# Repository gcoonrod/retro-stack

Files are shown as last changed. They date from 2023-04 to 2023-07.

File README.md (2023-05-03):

# retro-stack

A retro computer project based on stackable PCB boards. This project was largely inspired by Ben Eater's 6502 breadboard computer project.

## Project Objective

Design, prototype, and build an 8 bit computer roughly comparable to an Apple II or NES in capabilities.

### Hardware Design Goals

Create an 8 bit computer with the following basic capabilities:

- Stable at or near maximum frequency of the processor
- Modular (including reconfigurable address map)
- Character display via RS-232 Serial and LCD
- PS/2 Keyboard Input

Optional:

- Sound generation
- VGA video output
- 10baseT ethernet

### Software Design Goals

- Develop a strong understanding of Assembly programming
- Understand and implement the following protocols:
  - UART
  - SPI
  - PS/2
- Learn the basics of PLDs and CUPL to use in "glue logic"
- Develop a moderate to strong understanding of Atmel AVR MCU programming
- Implement a simple Operating System within the constraints of an 8 bit architecture
- Understand and implement both software and hardware interrupts

## Repository Layout

This repository contains all of the hardware and software assets in the following structure:

- [Hardware Schematics and PCB Layouts](./boards/)
- [Firmware](./firmware/)
- Tooling (TBD)
- Documentation (TBD)s

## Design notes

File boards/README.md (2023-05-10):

<!--
 Copyright 2023 Greg Coonrod
 
 Licensed under the Apache License, Version 2.0 (the "License");
 you may not use this file except in compliance with the License.
 You may obtain a copy of the License at
 
     http://www.apache.org/licenses/LICENSE-2.0
 
 Unless required by applicable law or agreed to in writing, software
 distributed under the License is distributed on an "AS IS" BASIS,
 WITHOUT WARRANTIES OR CONDITIONS OF ANY KIND, either express or implied.
 See the License for the specific language governing permissions and
 limitations under the License.
-->

# RetroStack - Boards

The RetroStack project currently includes the following boards based on a common [template](./retro-stack-template/):

- [Power Supply & 555 Clock](./retro-stack-power-clock/)
- [W65C02S CPU & High Speed Clock](./retro-stack-cpu/)
- [SRAM & ROM](./retro-stack-ram-rom/)
- [Arduino Mega Debug Shield](./retro-stack-debug-arduino-mega-shield/)
- [Debug & Status Display](./retro-stack-debug/)

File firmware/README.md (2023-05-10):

<!--
 Copyright 2023 Greg Coonrod
 
 Licensed under the Apache License, Version 2.0 (the "License");
 you may not use this file except in compliance with the License.
 You may obtain a copy of the License at
 
     http://www.apache.org/licenses/LICENSE-2.0
 
 Unless required by applicable law or agreed to in writing, software
 distributed under the License is distributed on an "AS IS" BASIS,
 WITHOUT WARRANTIES OR CONDITIONS OF ANY KIND, either express or implied.
 See the License for the specific language governing permissions and
 limitations under the License.
-->

# RetroStack Firmware

The RetroStack computer includes a W65C02S processor, PLDs, and Arduinos. Each of these components need software or firmware in order to operate. This folder contains that software broken up by logical "programs" or use-cases.

## Development and Debugging Utilities

- [Monitor](./arduino/monitor/) - Arduino Mega2560 based bus monitor and ROM emulator.
- [PLD Tester](./arduino/pld-tester/) - Arduino Nano Every based tool for testing an AT16V8B PLD.

## Programmable Logic

- [Address Decode](./pld/address-decode/) - CUPL files for the various PLDs.

## 6502 Applications

- [Memory Tester](./6502/memory-test/) - Verify current RAM/ROM address map.
- [IO Test](./6502/io-test/) - Use an LED bar and W65C22 VIA to display the output of an 8-bit counter.

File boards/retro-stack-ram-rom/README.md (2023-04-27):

<!--
 Copyright 2023 Greg Coonrod
 
 Licensed under the Apache License, Version 2.0 (the "License");
 you may not use this file except in compliance with the License.
 You may obtain a copy of the License at
 
     http://www.apache.org/licenses/LICENSE-2.0
 
 Unless required by applicable law or agreed to in writing, software
 distributed under the License is distributed on an "AS IS" BASIS,
 WITHOUT WARRANTIES OR CONDITIONS OF ANY KIND, either express or implied.
 See the License for the specific language governing permissions and
 limitations under the License.
-->

# RetroStack - RAM & ROM Module

This module contains RAM, ROM, and a PLD for address decoding.

## Schematic

Current schematic [pdf](./assets/schematic.pdf).

## PCB Layout & Render

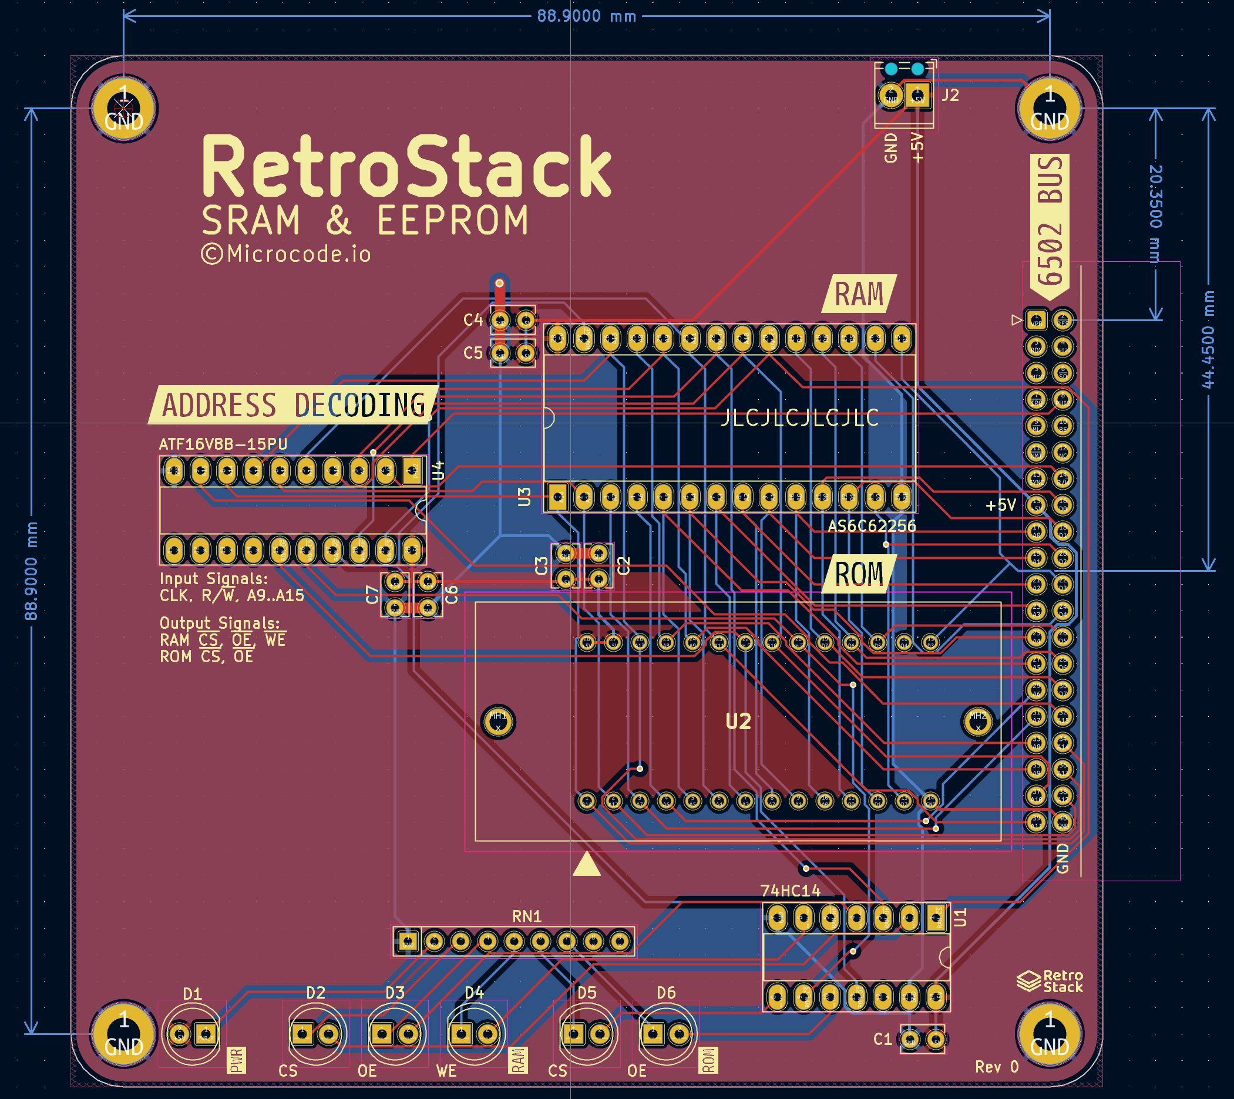
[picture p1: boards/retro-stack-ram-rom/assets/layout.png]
layout


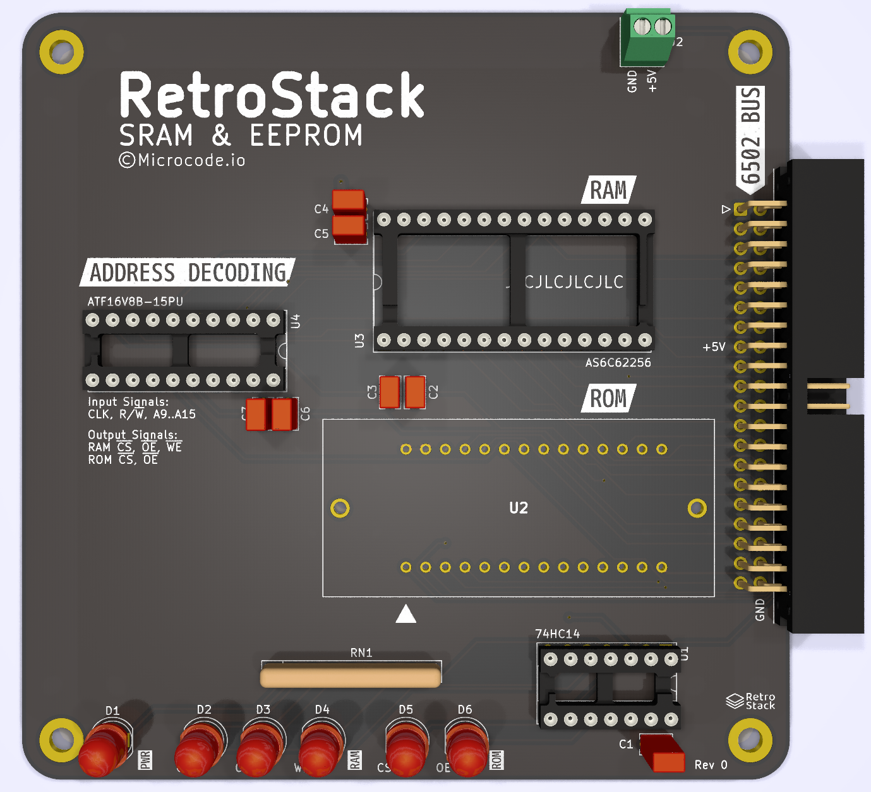
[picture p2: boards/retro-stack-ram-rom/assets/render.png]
render


## Known Issues

N/A

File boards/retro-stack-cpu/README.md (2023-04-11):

# RetroStack - W65C02S CPU & High Speed Clock Module

This module contains the W65C02S CPU, a selectable high speed oscillator, and a selectable DS1813 reset signal manager.

## Schematic

Current schematic [pdf](./assets/schematic.pdf).

## PCB Layout & Render

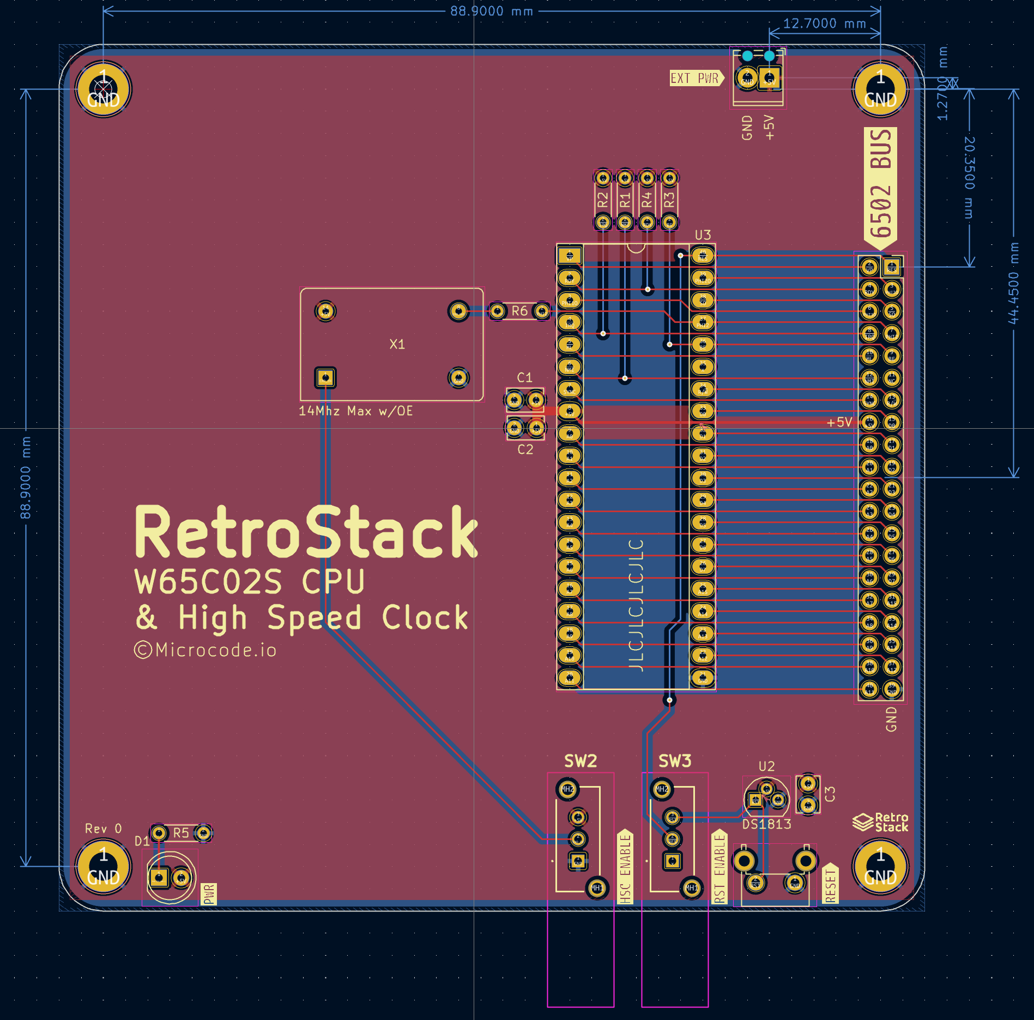
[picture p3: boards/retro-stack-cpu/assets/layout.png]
layout


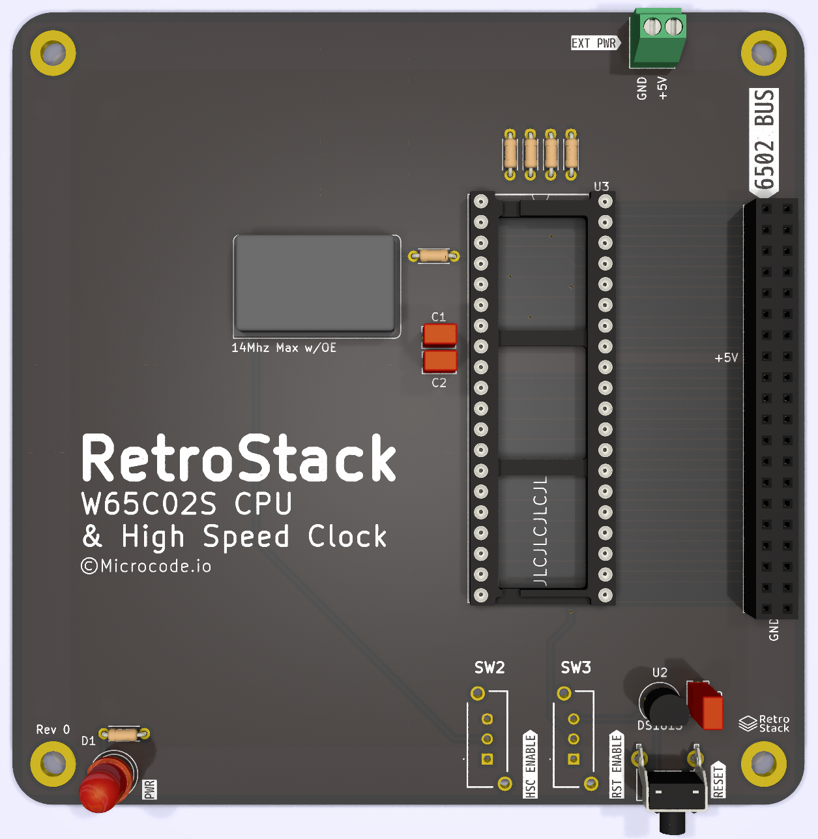
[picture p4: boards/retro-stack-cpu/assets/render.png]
render


## Known Issues

N/A

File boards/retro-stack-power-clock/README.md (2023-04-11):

# RetroStack - Power & Clock Module

This module is based on the 555 clock circuit used in Ben Eater's 8-bit and 6502 computer projects.

## Schematic

Current schematic [pdf](./assets/schematic.pdf).

## PCB Layout & Render

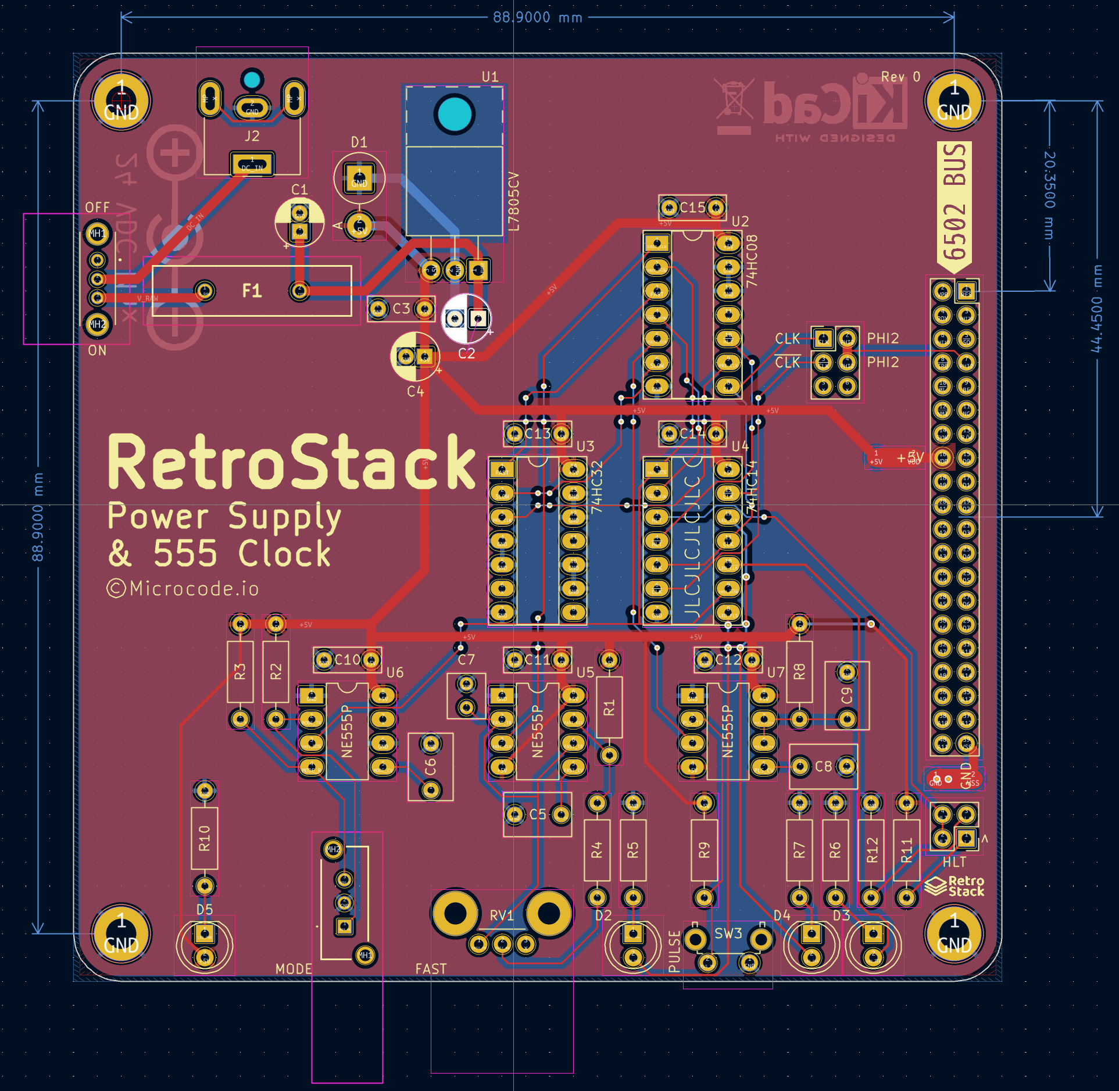
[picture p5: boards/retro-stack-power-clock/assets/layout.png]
layout


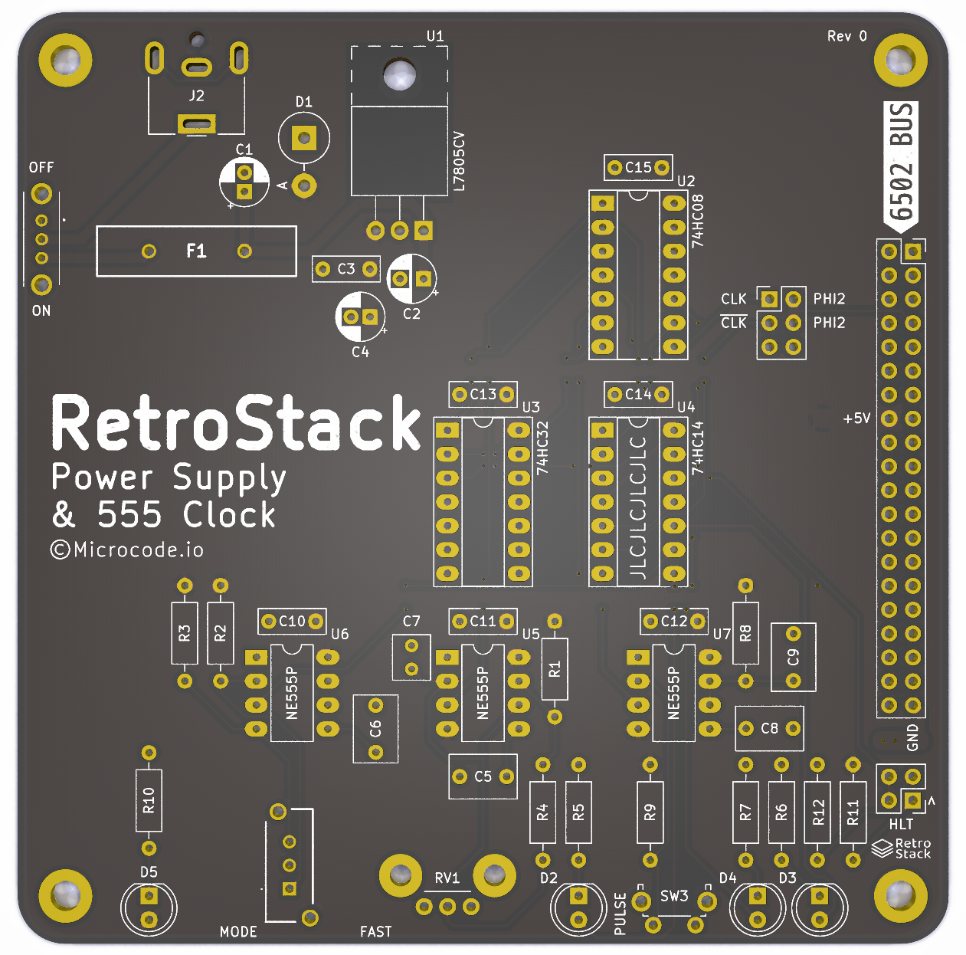
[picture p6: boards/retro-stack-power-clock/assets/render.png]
render


## Known Issues

- PTC is oversized.
- TVS diode is oversized.
- Need knob for RV1.
- Need 2.54mm pitch header jumpers.
- Add more detail to silkscreen.
- Remove Net ties.

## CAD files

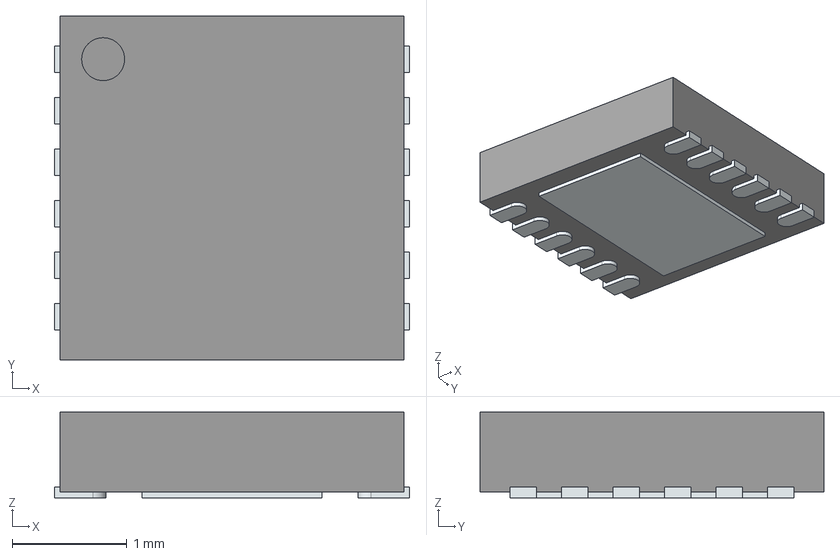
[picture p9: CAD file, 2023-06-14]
boards/parts/3D/FT234XD-R.step
3.10 x 3.00 x 0.75 mm
ThermalPin
PinsArrayLR

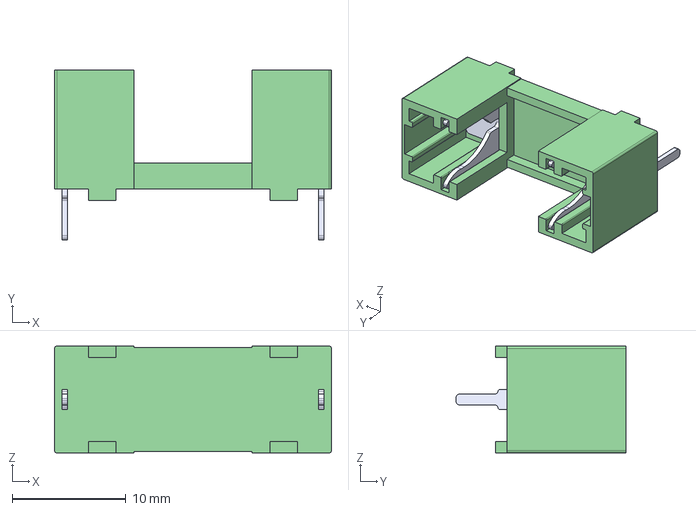
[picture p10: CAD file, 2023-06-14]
boards/parts/3D/0PTF0078P.step
24.4 x 15.0 x 9.40 mm

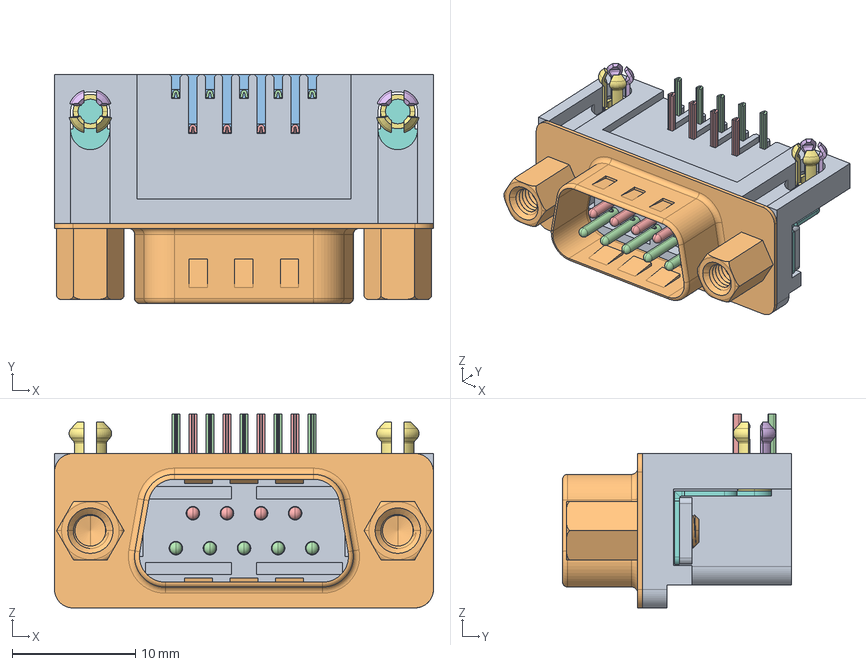
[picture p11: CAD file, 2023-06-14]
boards/parts/3D/L717SDE09PA4CH3F.step
30.8 x 18.6 x 15.8 mm
MALE
COVER
TERMINAL-22 x 5
TERMINAL-11 x 4
YUCHA x 2
CLINTNUT-7 x 2
SCREW x 2

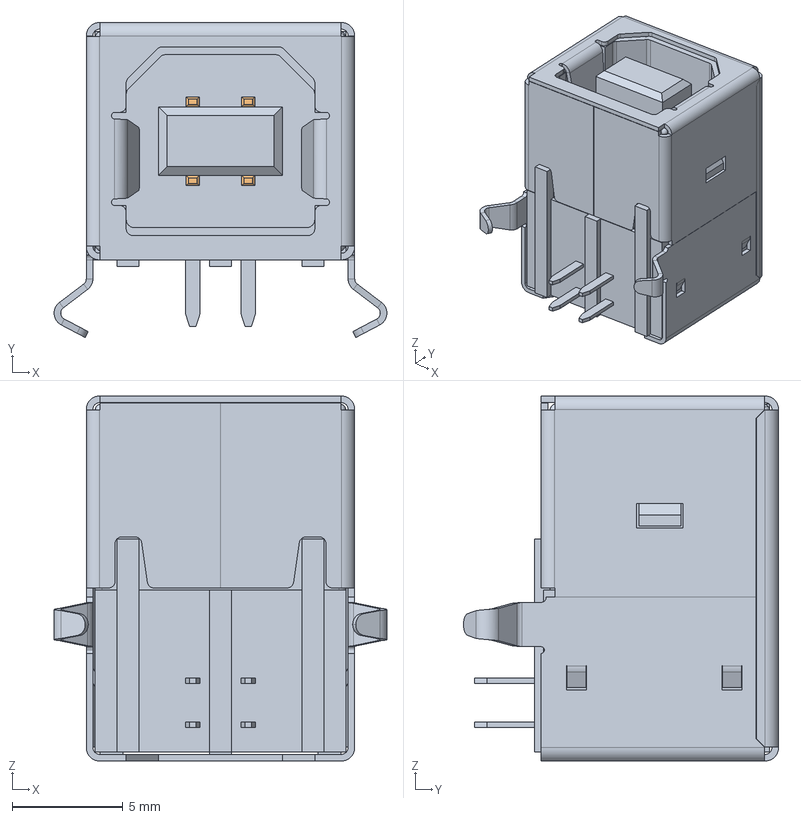
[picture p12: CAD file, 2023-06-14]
boards/parts/3D/UJ2-BH-1-TH.step
15.0 x 14.2 x 16.5 mm

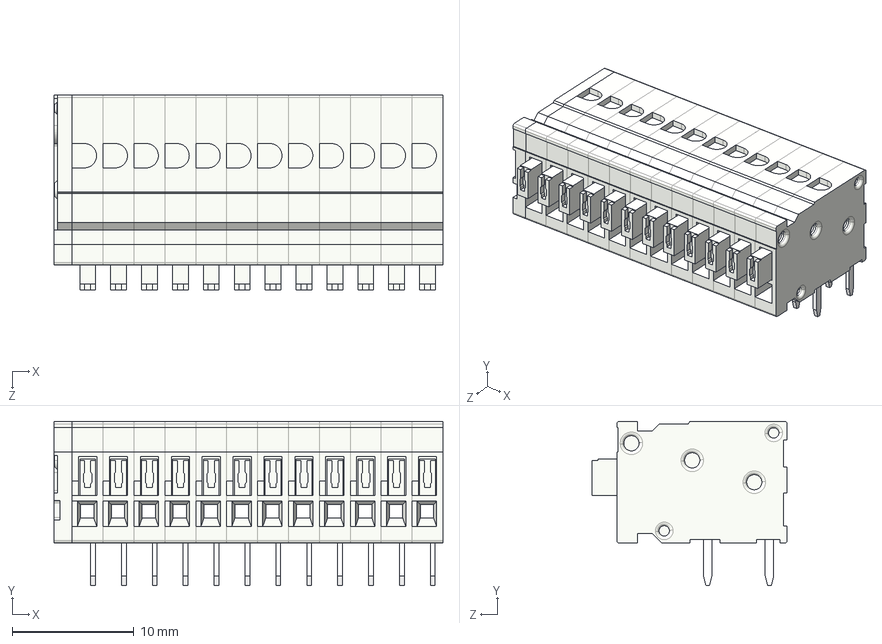
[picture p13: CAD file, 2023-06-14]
boards/parts/3D/CUI_DEVICES_TBL009-254-12GY-2GY.step
32.0 x 13.5 x 16.1 mm
TBL009-254 - END CAP_Gray
TBL009-254 - BODY_Gray x 12
TBL009-254 - PUSH BUTTON_Gray x 12

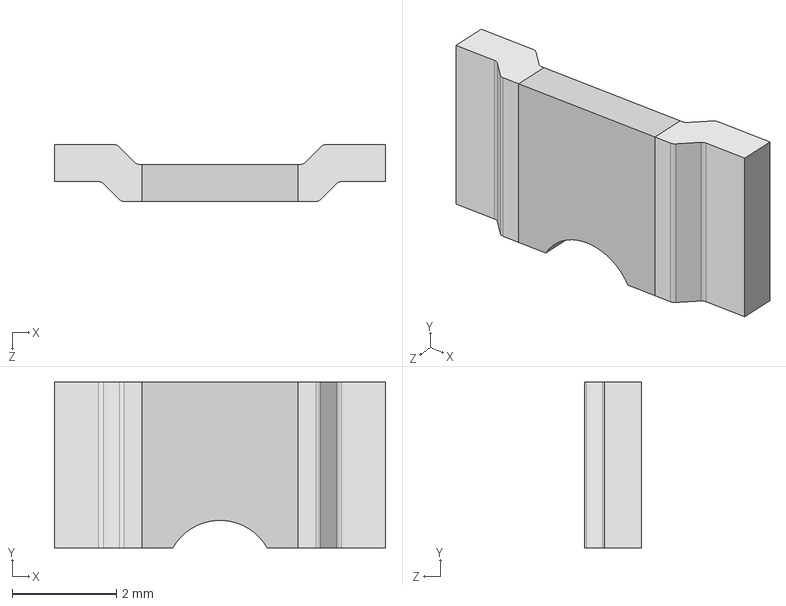
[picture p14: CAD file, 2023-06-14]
boards/parts/3D/WSLF25122L000FEA.stp
6.35 x 3.17 x 1.09 mm

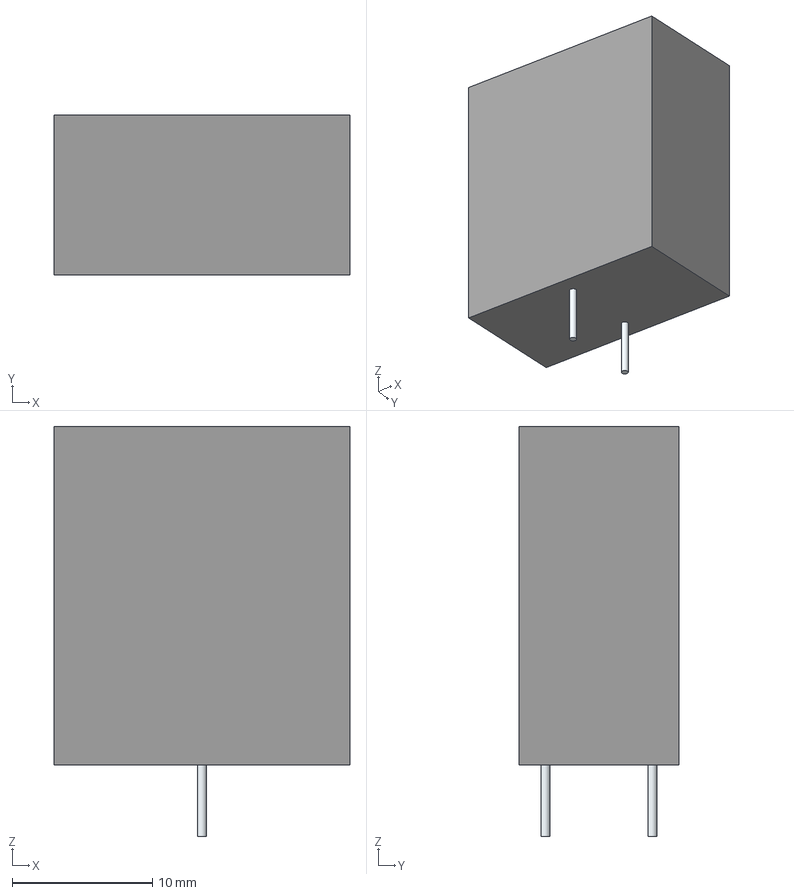
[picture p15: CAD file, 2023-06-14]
boards/parts/3D/PE-54038NL.step
21.1 x 11.4 x 29.2 mm
Leads x 2

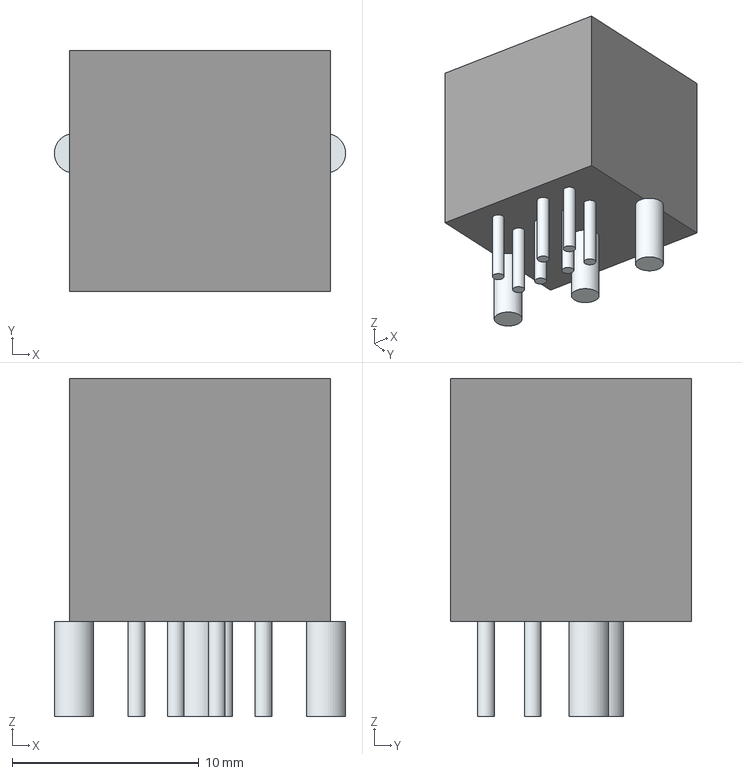
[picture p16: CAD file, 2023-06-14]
boards/parts/3D/KMDGX-7S-BS.stp
15.6 x 12.9 x 18.1 mm
Leads x 10

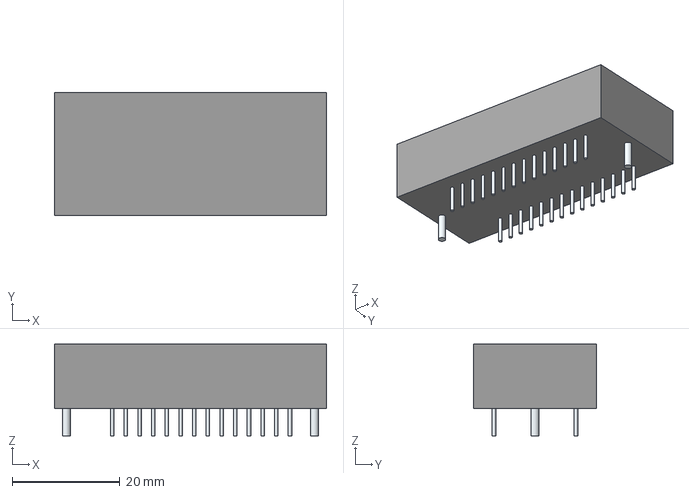
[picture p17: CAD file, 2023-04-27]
boards/parts/3D/28-6554-10.step
50.5 x 22.9 x 17.0 mm
Leads x 30

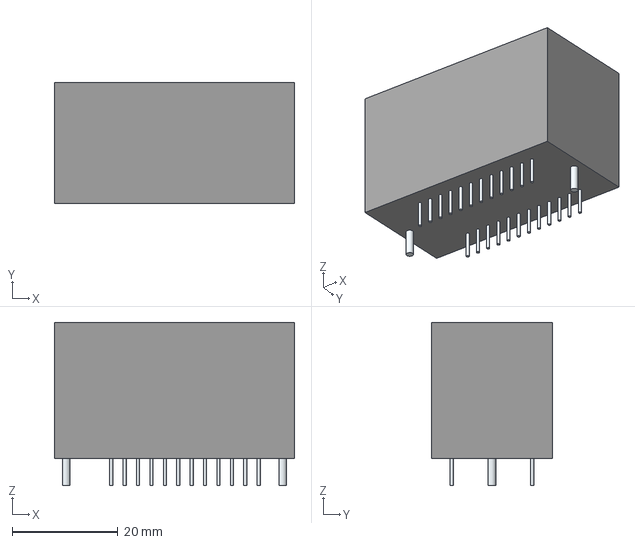
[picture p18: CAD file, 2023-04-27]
boards/parts/3D/24-6554-10.step
45.5 x 22.9 x 30.9 mm
Leads

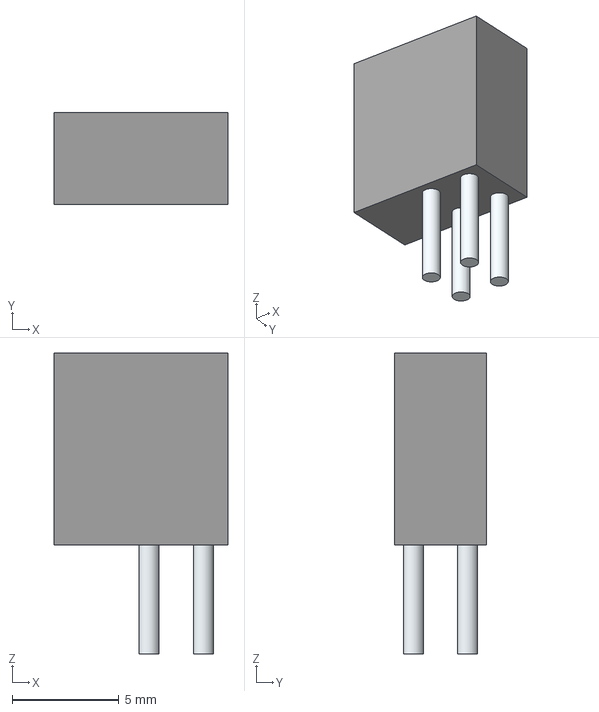
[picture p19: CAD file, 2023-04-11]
boards/parts/3D/553-0121F.step
8.13 x 4.32 x 14.1 mm
Leads x 4

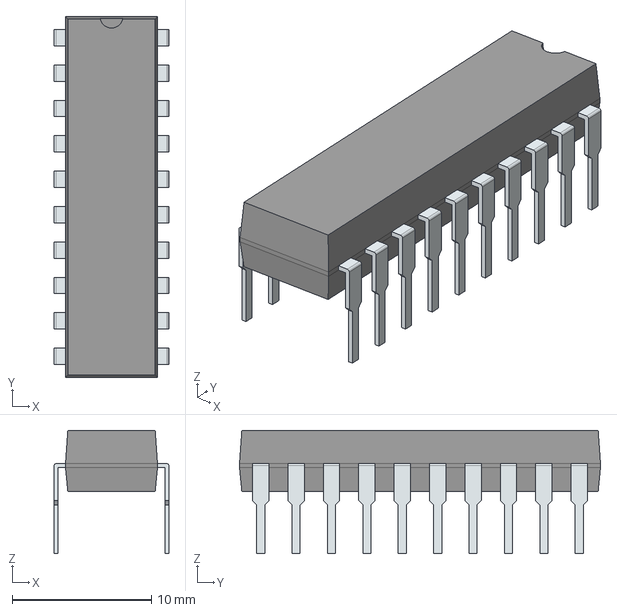
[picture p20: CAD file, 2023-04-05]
boards/parts/3D/ATF16V8B-15PU.step
8.23 x 25.9 x 8.83 mm
PinsArrayLR

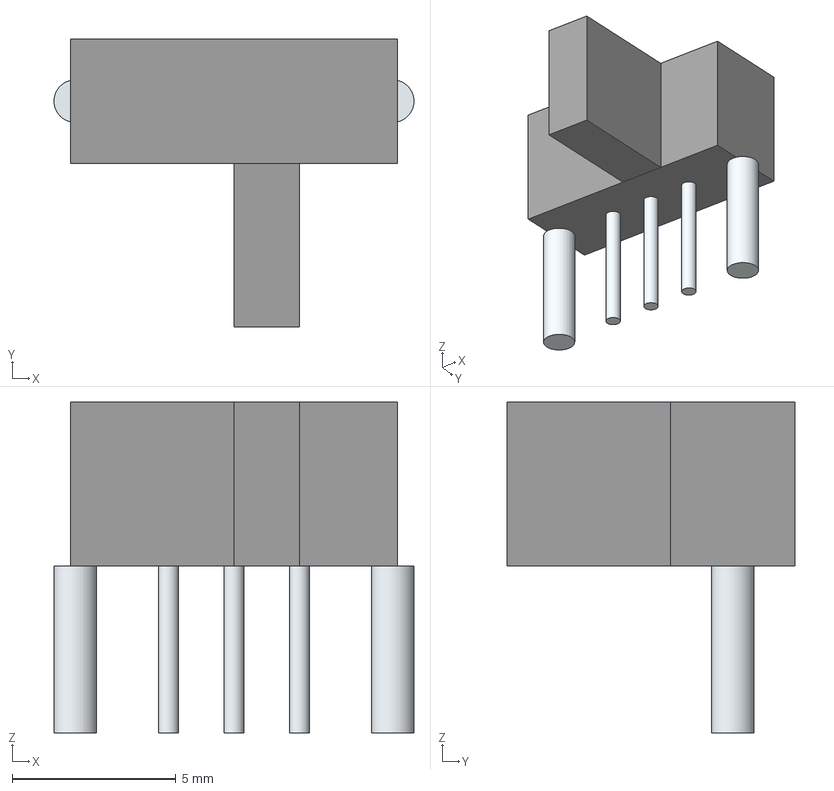
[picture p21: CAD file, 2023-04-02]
boards/parts/3D/EG1213.step
11.0 x 8.80 x 10.1 mm
Leads x 5

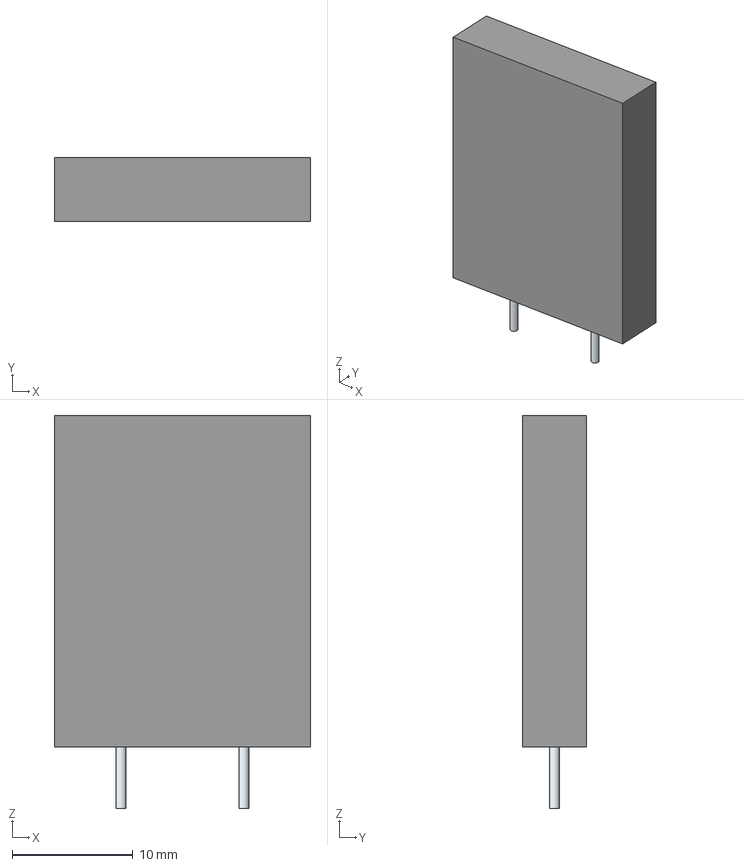
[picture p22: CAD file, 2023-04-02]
boards/parts/3D/LVR125S-240.step
21.2 x 5.30 x 32.5 mm
Leads

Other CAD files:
boards/parts/3D/2002101855.stp
boards/parts/3D/532702B02500G.step
boards/parts/3D/0PTF0078P.stp
boards/parts/3D/12401832E402A.step
boards/parts/3D/12401832E402A.stp
boards/parts/3D/24-6554-10.stp
boards/parts/3D/28-6554-10.stp
boards/parts/3D/529802B02500G.step
boards/parts/3D/529802B02500G.stp
boards/parts/3D/532702B02500G.stp
boards/parts/3D/553-0121F.stp
boards/parts/3D/8428-11B1-RK-TP.stp
boards/parts/3D/8444-11B1-RK-TP.stp
boards/parts/3D/ATF16V8B-15PU.stp
boards/parts/3D/EG1213.stp
boards/parts/3D/FT234XD-R.stp
boards/parts/3D/L717SDE09PA4CH3F.stp
boards/parts/3D/LVR125S-240.stp
boards/parts/3D/PE-54038NL.stp
boards/parts/3D/UJ2-BH-1-TH.stp

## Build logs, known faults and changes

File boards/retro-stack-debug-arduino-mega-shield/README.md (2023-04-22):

# RetroStack - Arduino Mega Debug Shield

This Arduino Mega shield is designed to easily connect to the RetroStack Debug board via a 40 pin IDC connector.

## Schematic

Current schematic [pdf](./assets/schematic.pdf).

## PCB Layout & Render

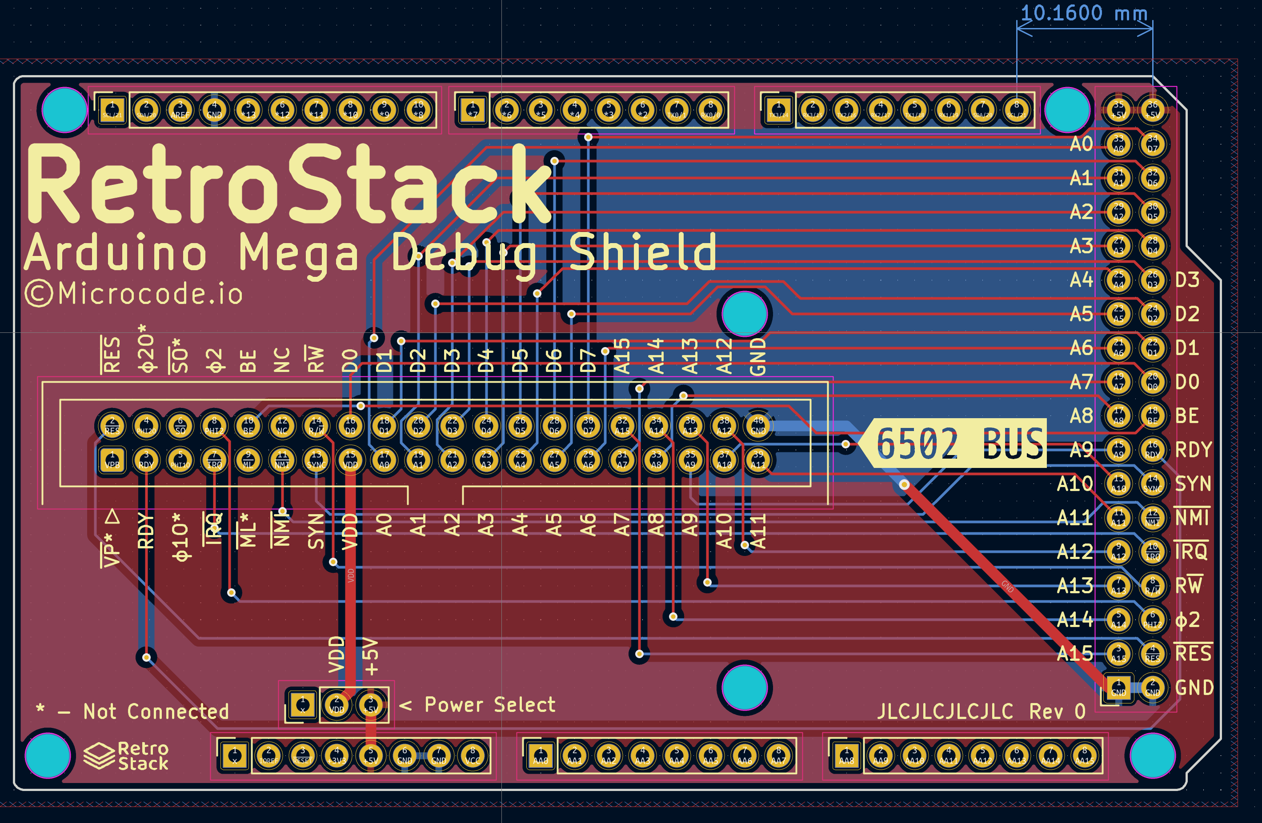
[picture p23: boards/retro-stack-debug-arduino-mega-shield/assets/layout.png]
layout


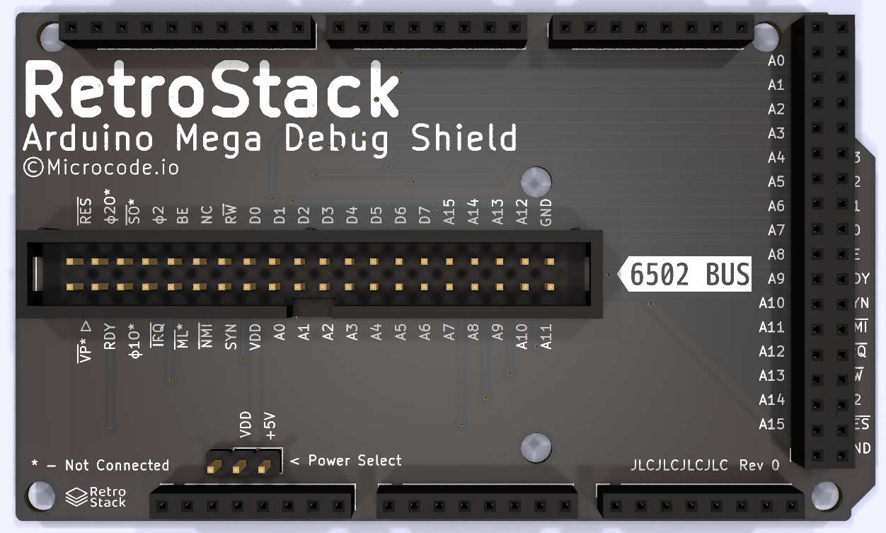
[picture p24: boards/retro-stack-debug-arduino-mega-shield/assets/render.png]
render


## Known Issues

- 6502 Bus is backwards. Pin 1 should be RESB but is VPB instead.
- PHI2 should be connected to one of the digital pins that support interrupts (2, 3, etc)
  - Consider adding jumpers to send a few signals to interrupt pins.
- Power seems to be leaking between the arduino and the RetroStack. Needs diodes?

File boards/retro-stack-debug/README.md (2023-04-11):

# RetroStack - Debug Interface & Signal Monitor Module

This module provides a 40 pin IDC connection for use with an external debugging tool/circuit. In addition, all of the Address and Data signals and most of the control signals are routed through buffers to drive LEDs. The buffers can be disabled by the Display switch in the upper left when operating at higher speeds.

## Schematic

Current schematic [pdf](./assets/schematic.pdf).

## PCB Layout & Render

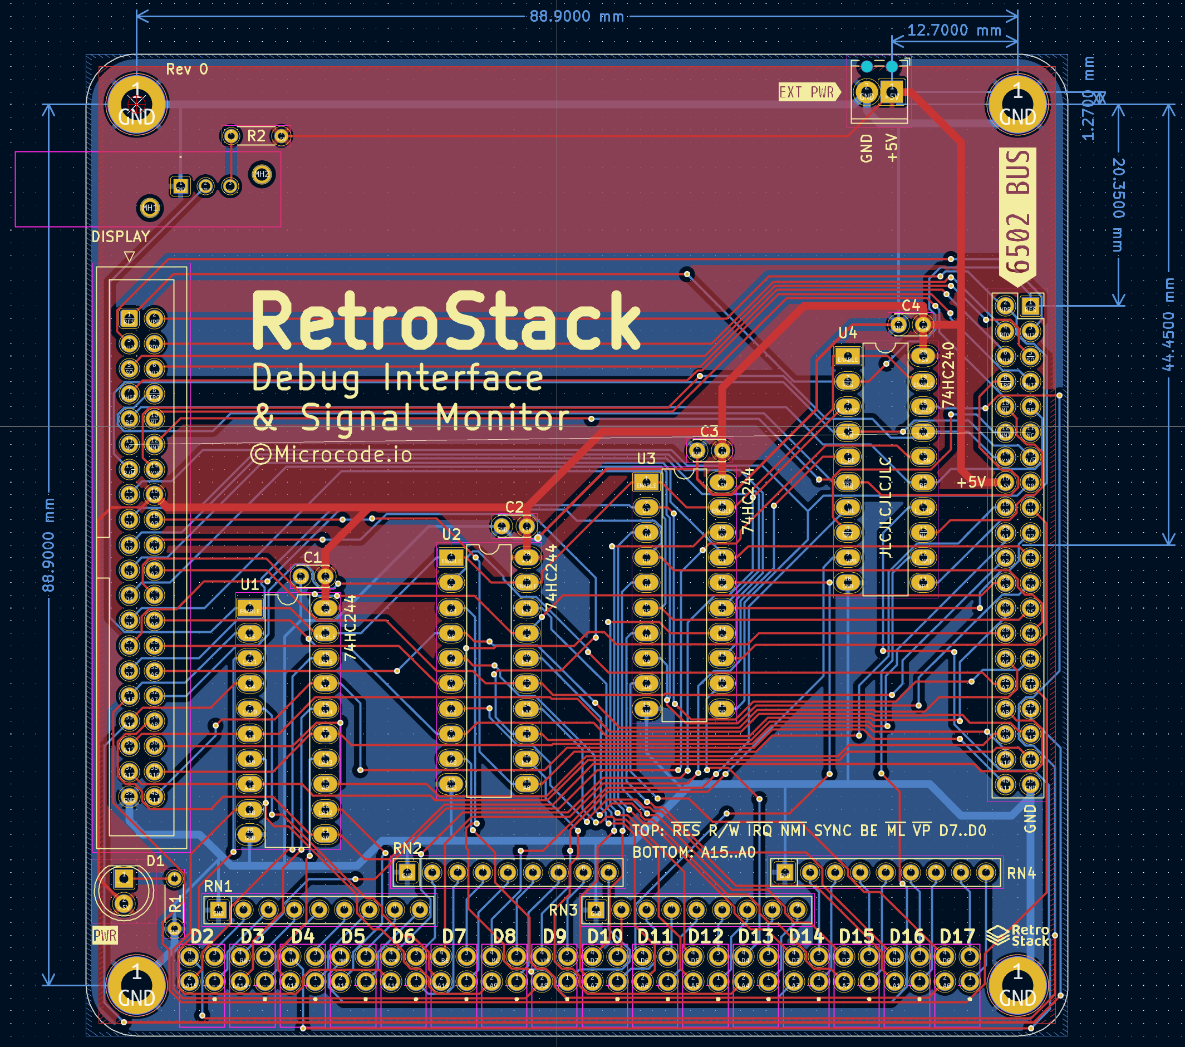
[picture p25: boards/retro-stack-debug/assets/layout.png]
layout


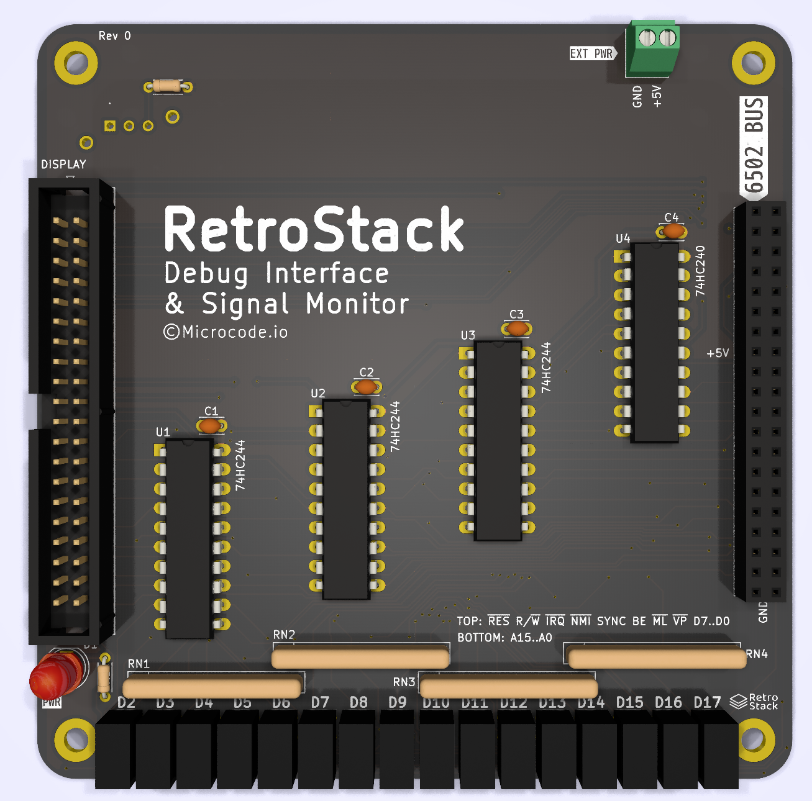
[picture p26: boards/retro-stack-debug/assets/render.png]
render


## Known Issues

N/A

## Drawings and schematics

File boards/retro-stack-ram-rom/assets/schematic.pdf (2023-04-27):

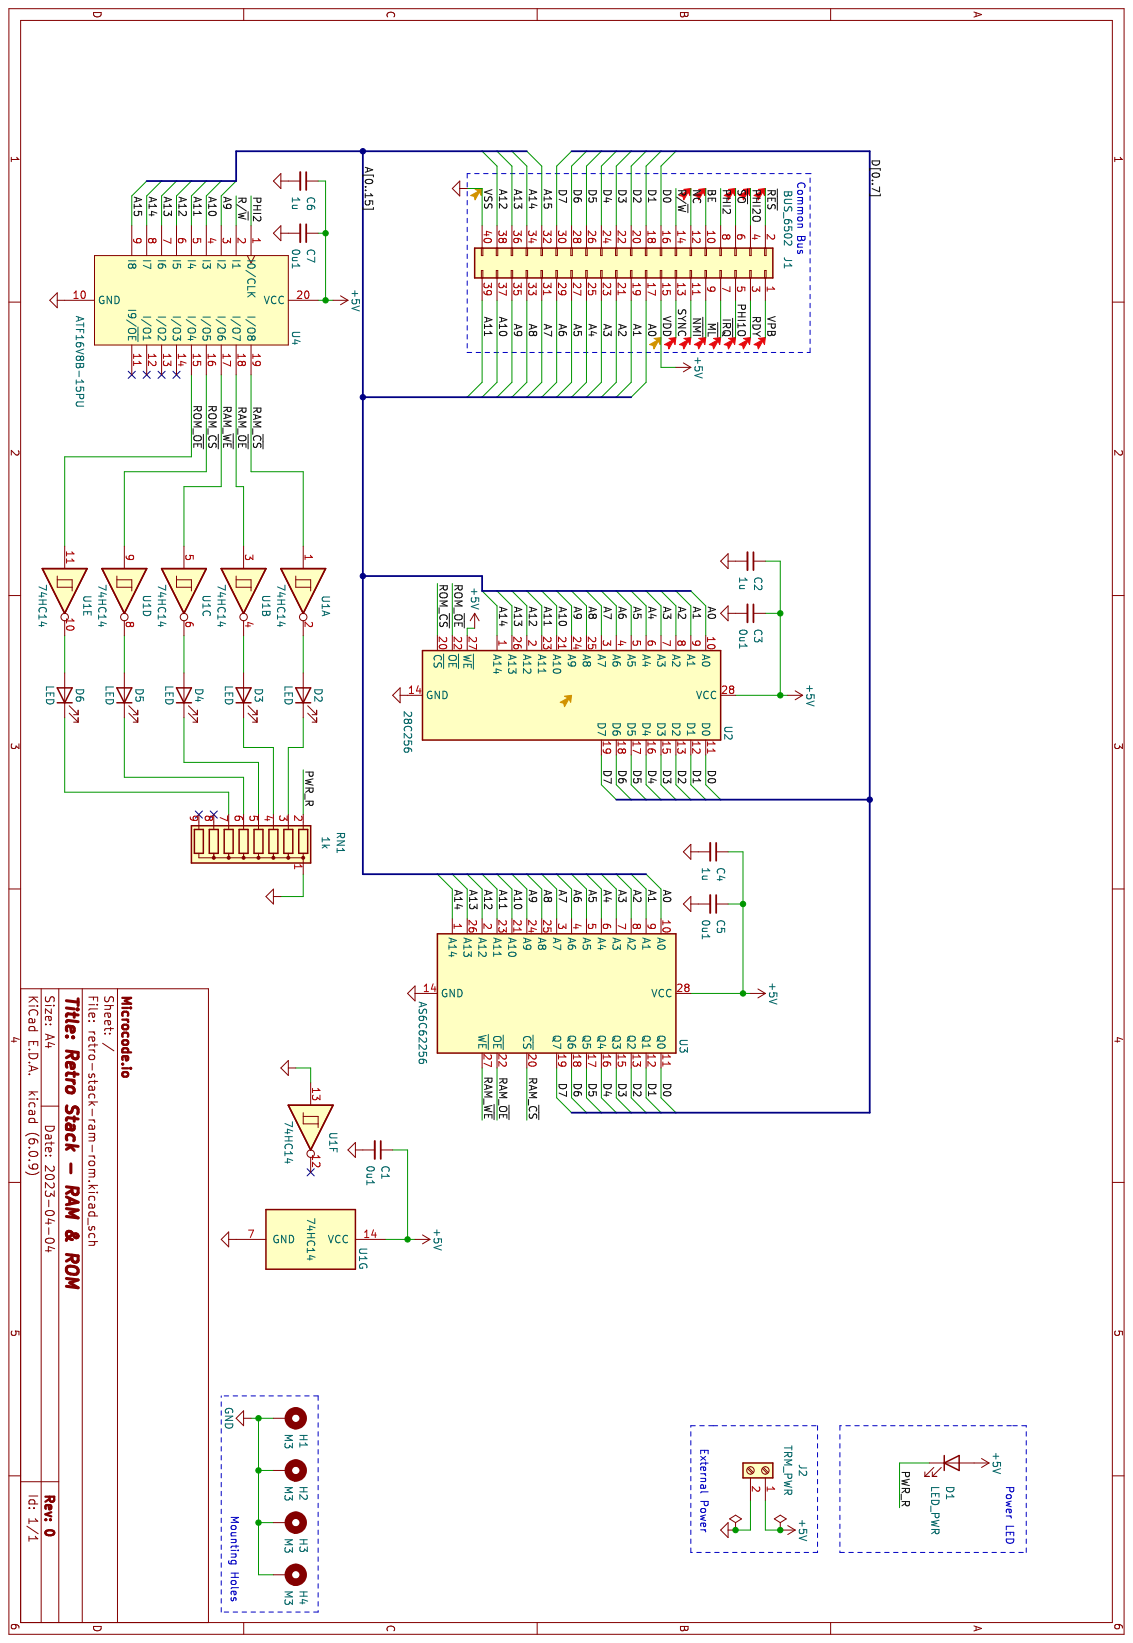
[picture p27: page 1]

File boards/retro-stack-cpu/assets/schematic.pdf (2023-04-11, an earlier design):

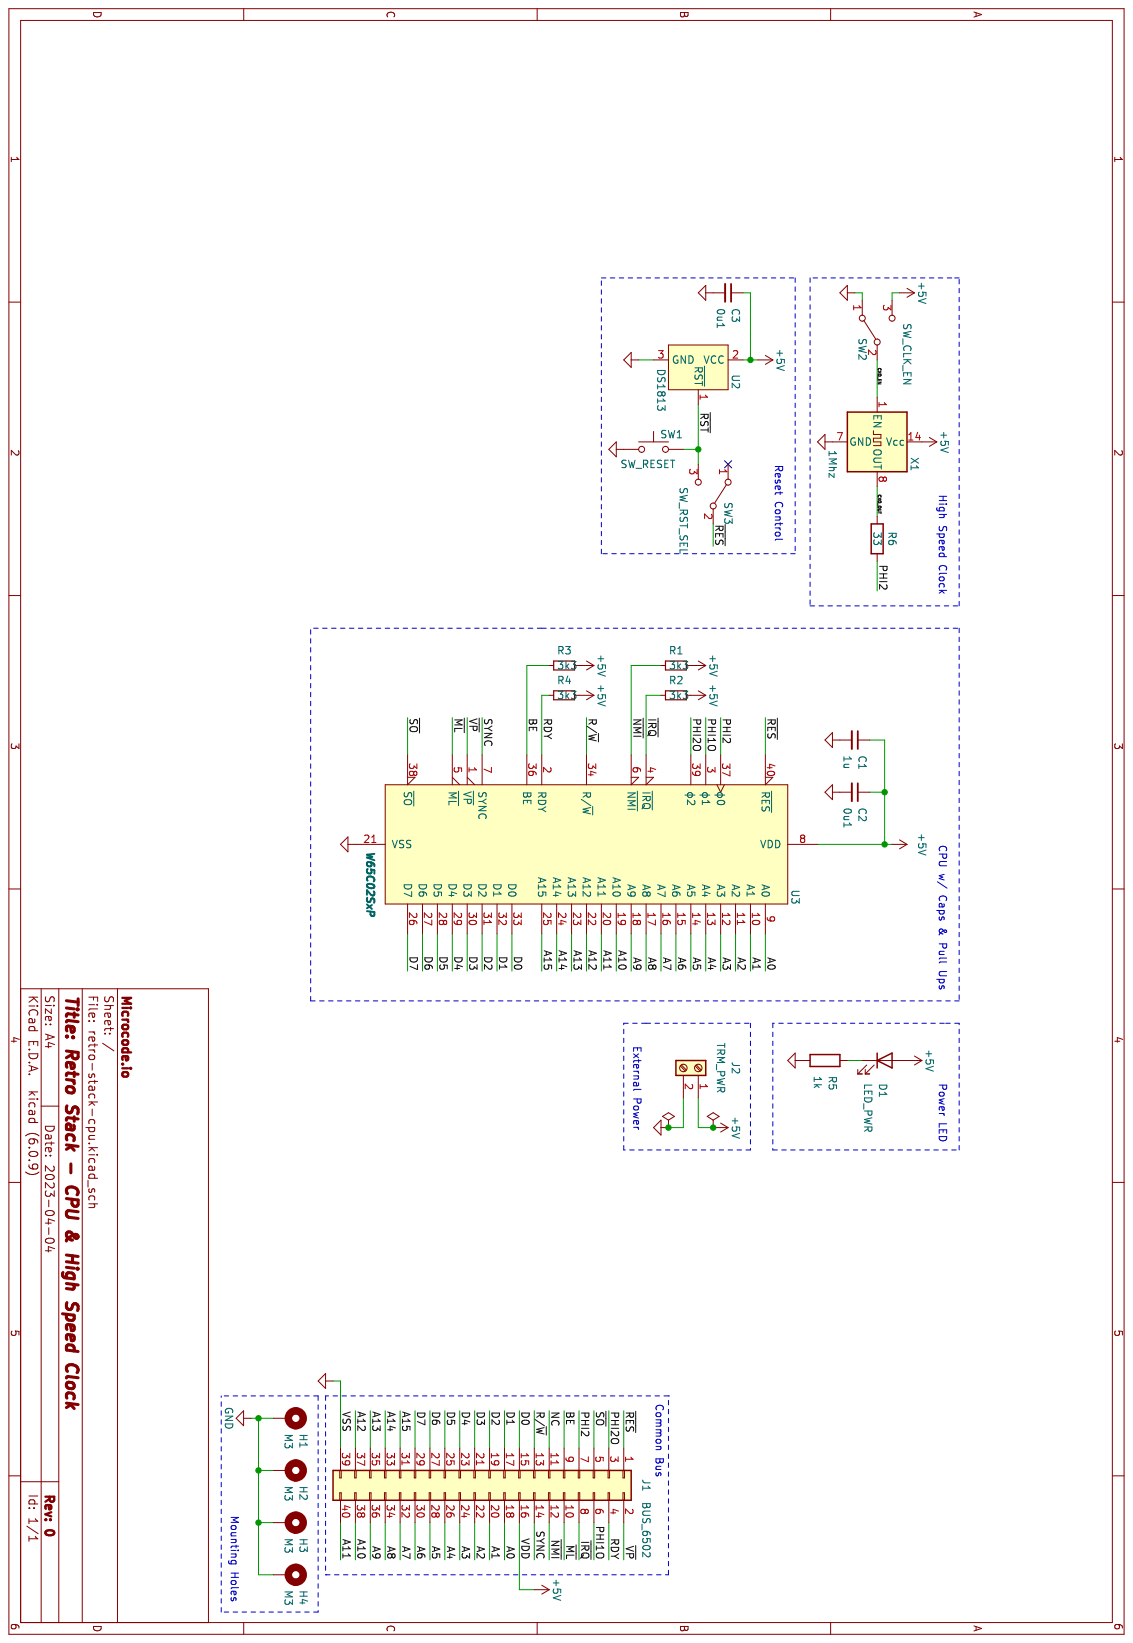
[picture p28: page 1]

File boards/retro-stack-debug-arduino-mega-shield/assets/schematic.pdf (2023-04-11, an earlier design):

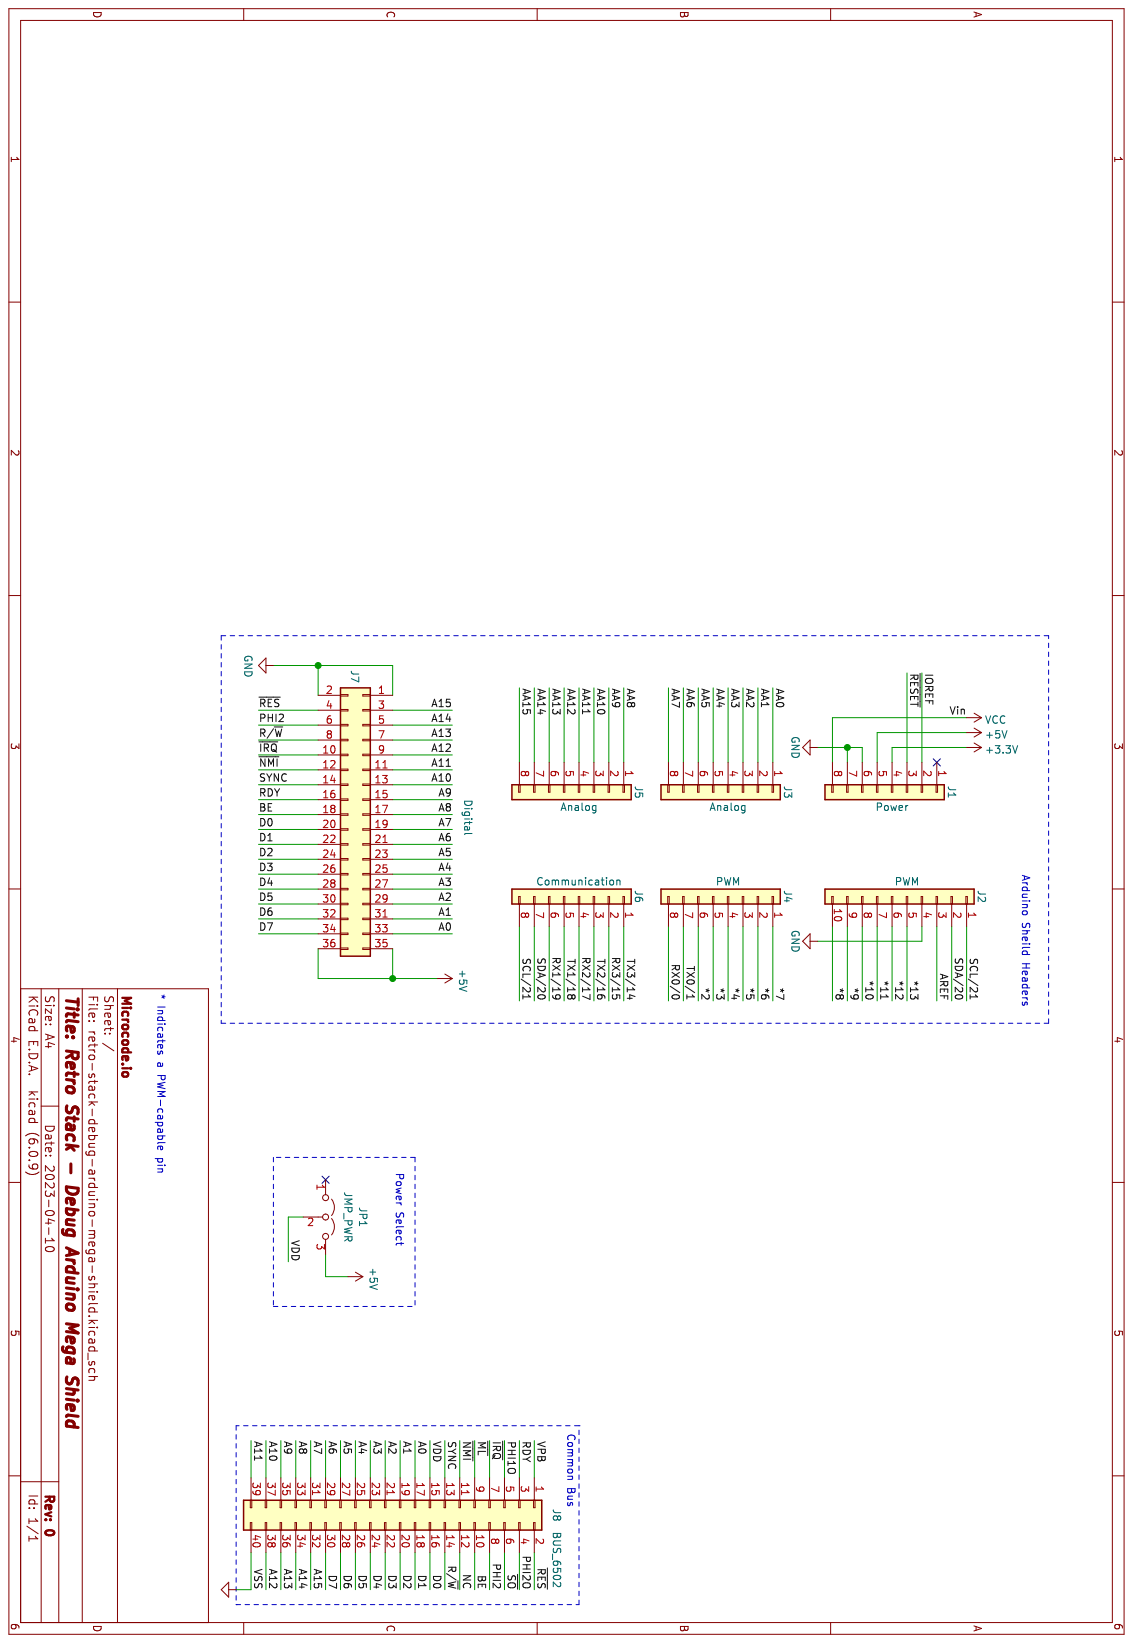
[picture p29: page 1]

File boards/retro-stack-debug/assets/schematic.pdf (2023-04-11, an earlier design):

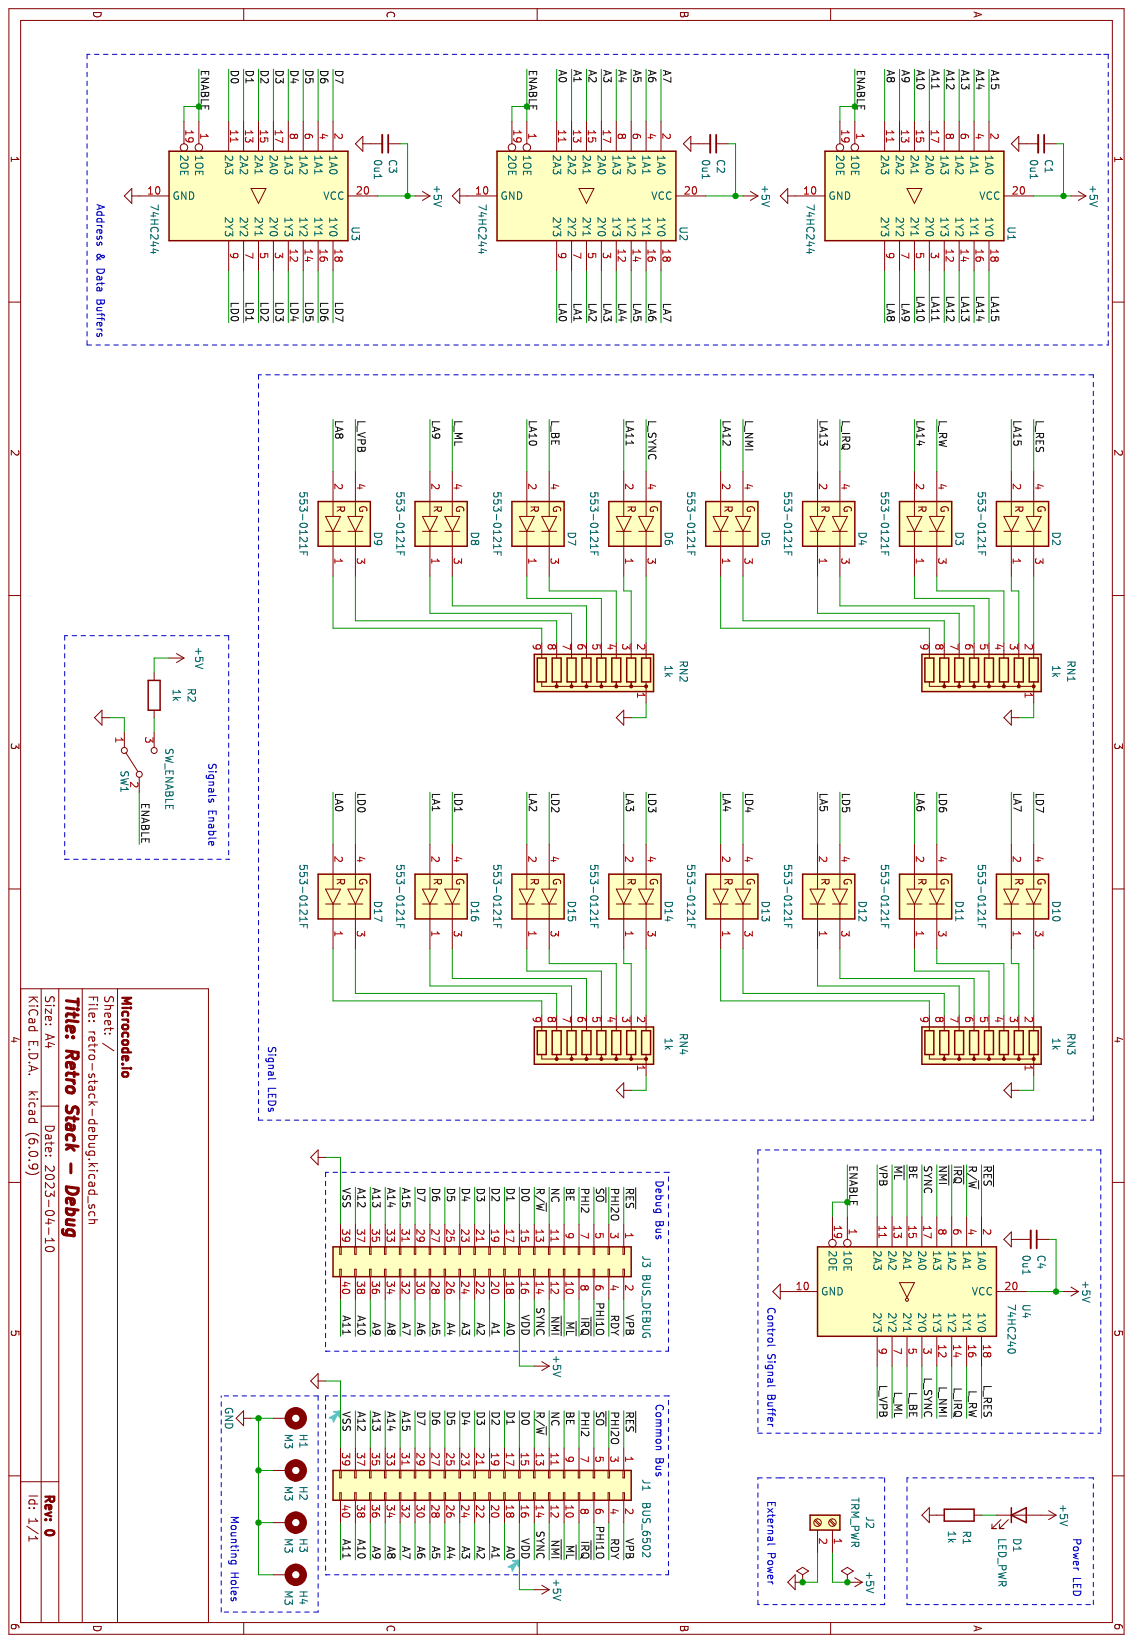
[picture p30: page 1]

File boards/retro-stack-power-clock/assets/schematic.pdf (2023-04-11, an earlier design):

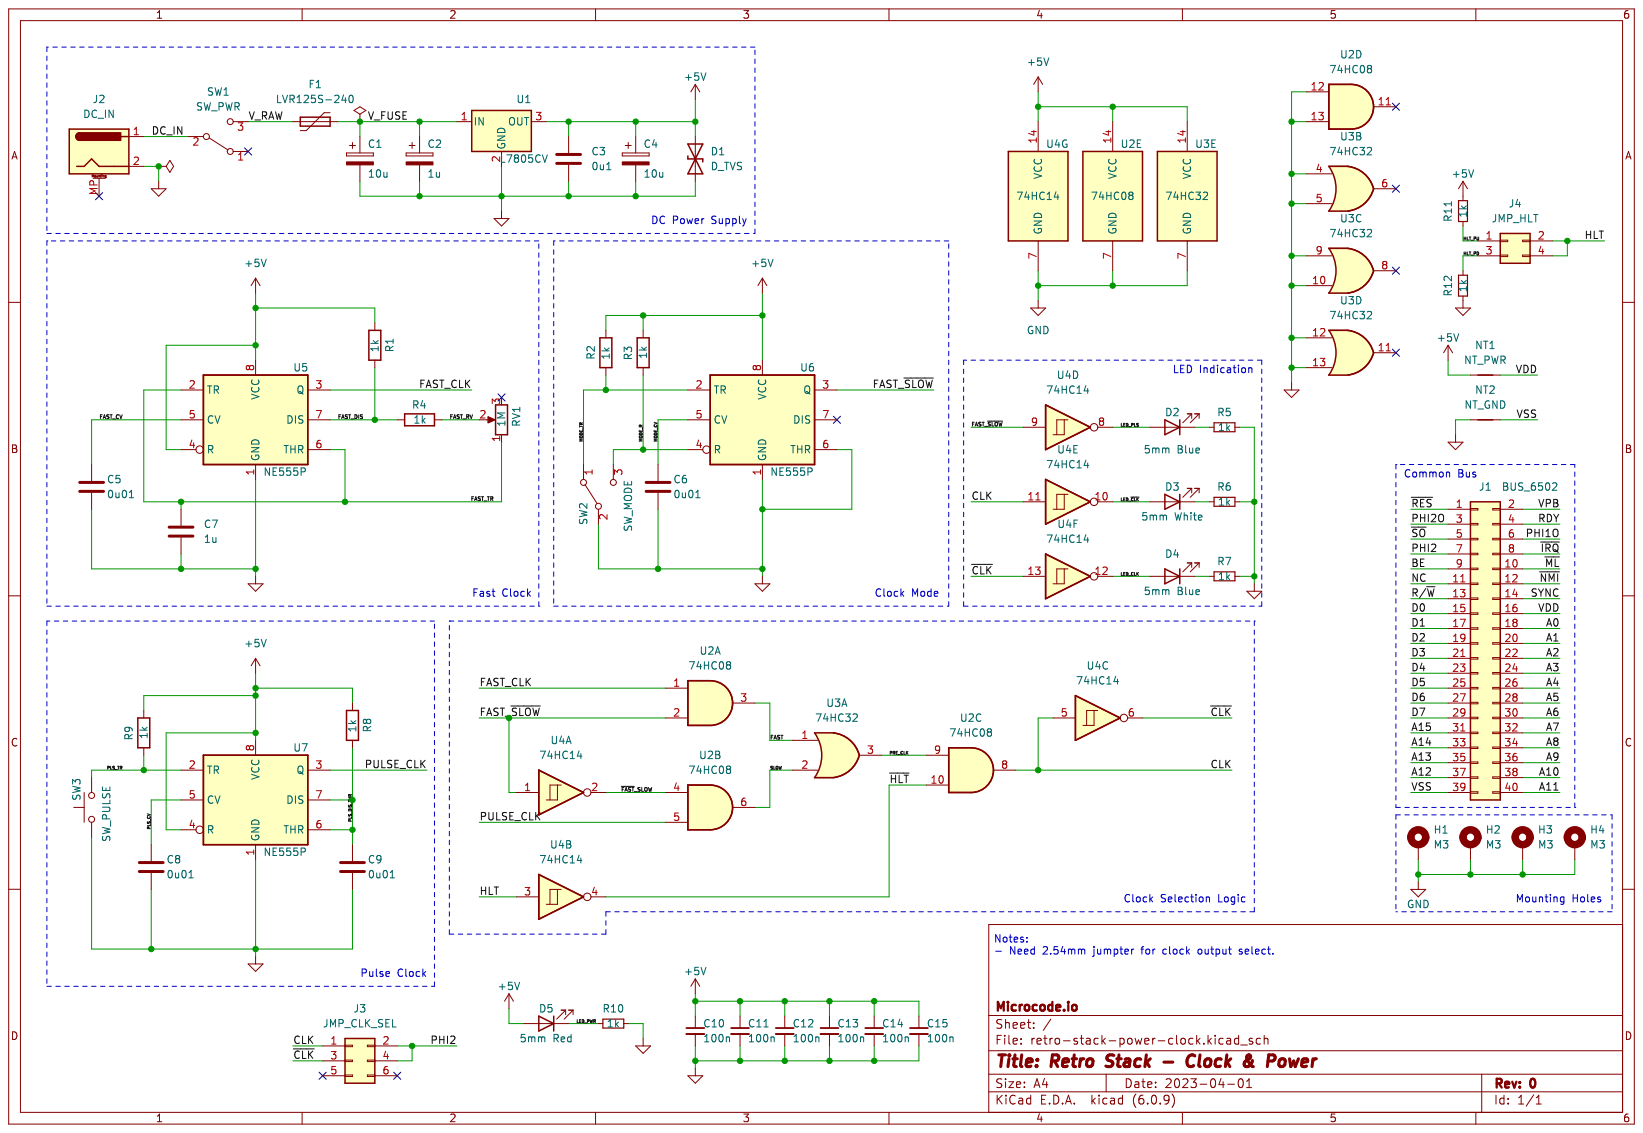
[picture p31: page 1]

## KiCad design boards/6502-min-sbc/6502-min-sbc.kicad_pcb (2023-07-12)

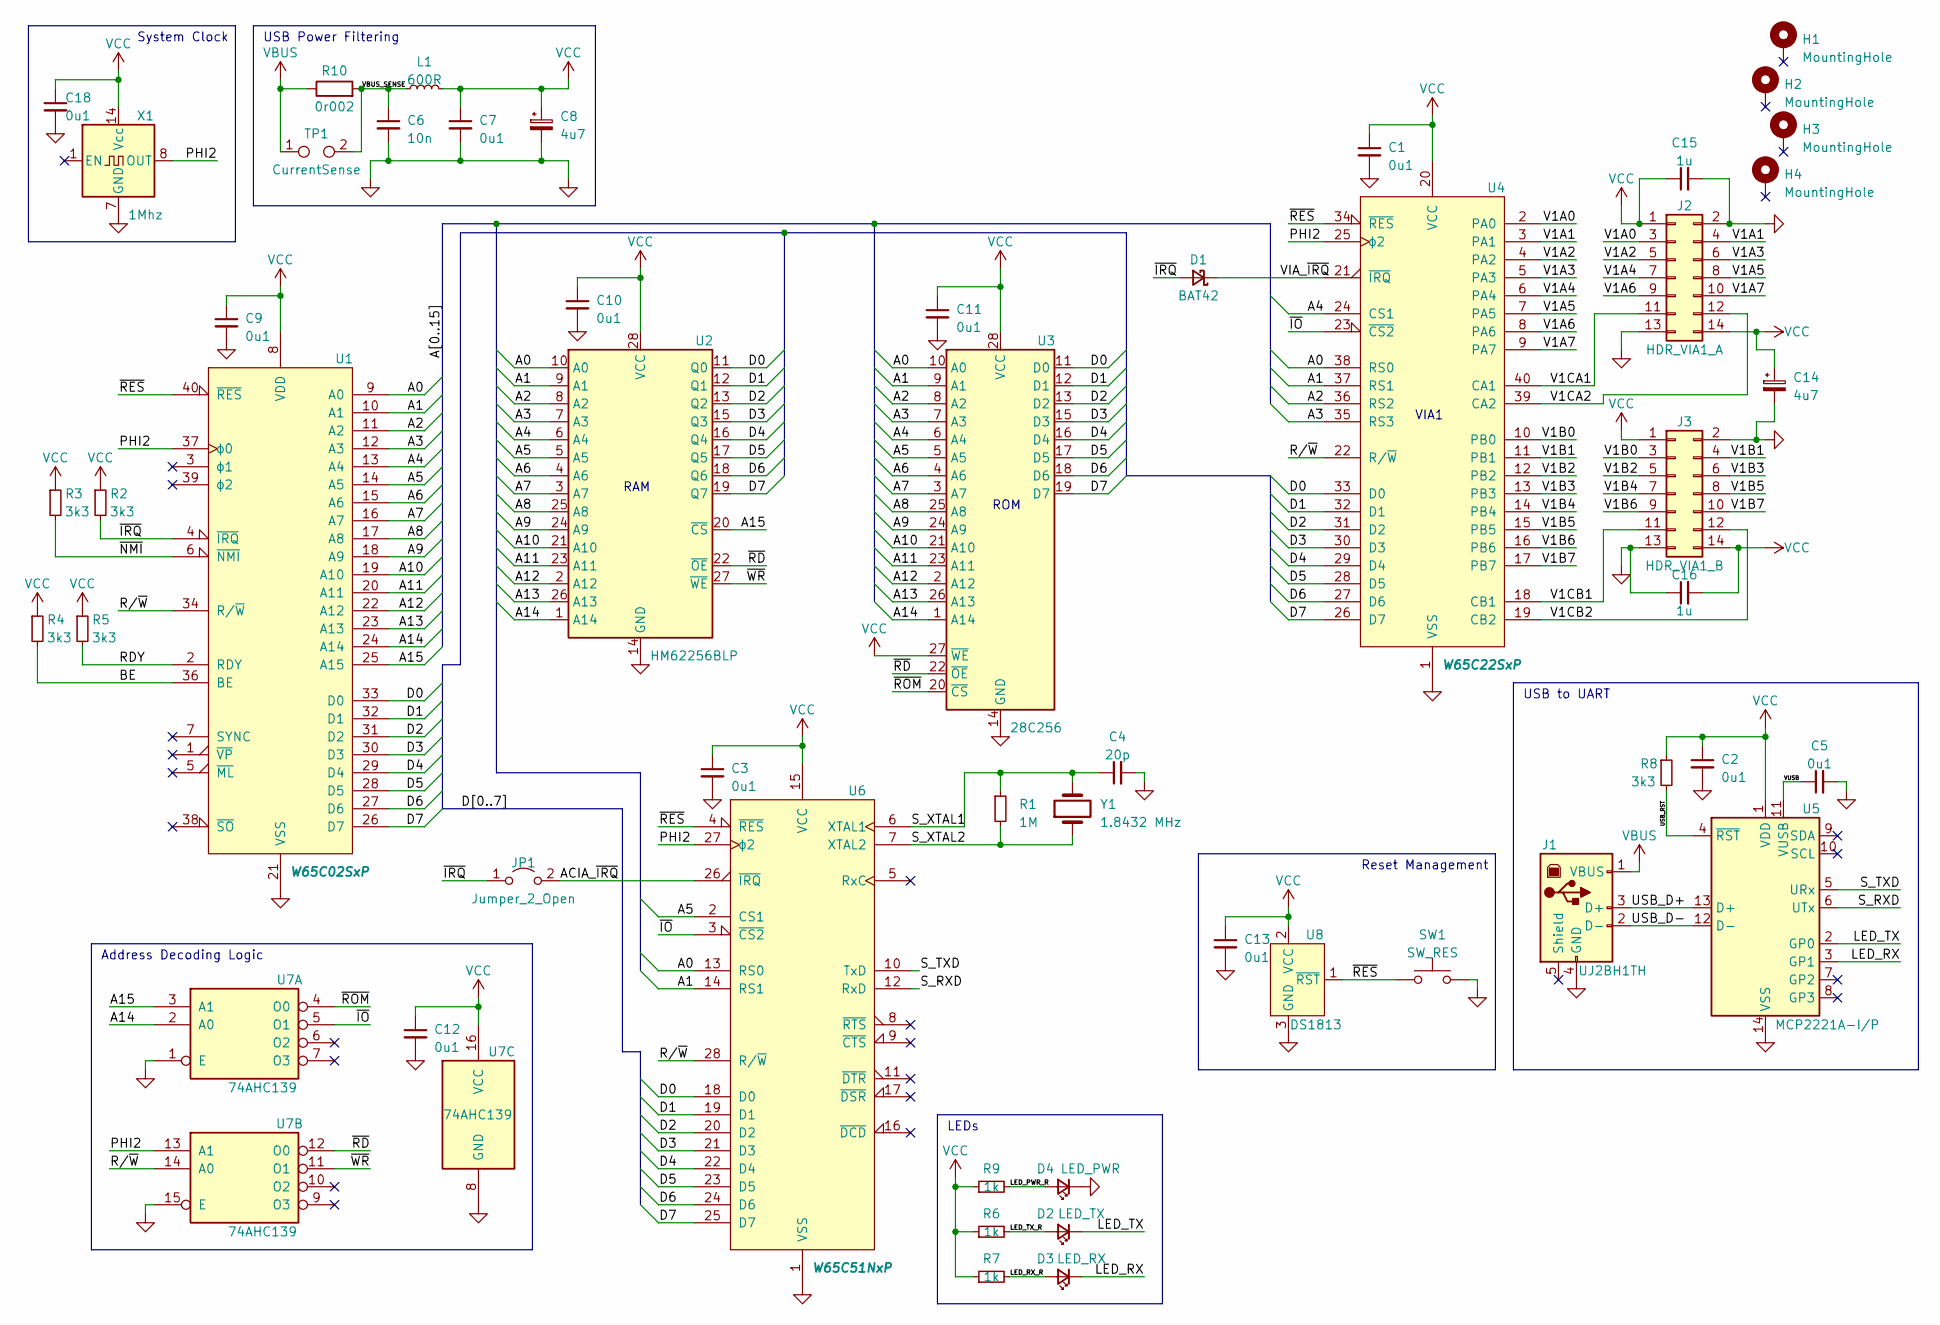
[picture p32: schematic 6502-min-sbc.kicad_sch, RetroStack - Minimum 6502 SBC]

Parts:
C1, C2, C3, C5, C7, C9, C10, C11, C12, C13, C18: 0u1; C_Rect_L4.0mm_W2.5mm_P2.50mm; Manufacturer Part K104K15X7RF5TL2
C4: 20p; C_Rect_L4.6mm_W3.8mm_P2.50mm_MKS02_FKP02; Manufacturer Part C315C200J3G5TA
C6: 10n; C_Rect_L4.0mm_W2.5mm_P2.50mm; Manufacturer Part K103K10X7RF53L2
C8, C14: 4u7; CP_Radial_D5.0mm_P2.50mm; Manufacturer Part ECE-A1VKS4R7I
C15, C16: 1u; C_Rect_L4.6mm_W3.0mm_P2.50mm_MKS02_FKP02; Manufacturer Part FG18X7R1E105KRT06
D1: BAT42; D_DO-35_SOD27_P7.62mm_Horizontal; Manufacturer Part BAT42
D2: LED_TX; LED_D5.0mm; Manufacturer Part WP7113YT
D3: LED_RX; LED_D5.0mm; Manufacturer Part WP7113YT
D4: LED_PWR; LED_D5.0mm; Manufacturer Part WP7113YT
H1, H2, H3, H4: MountingHole; MountingHole_3.2mm_M3_Pad
J1: UJ2BH1TH; Manufacturer Part UJ2-BH-1-TH
J2: HDR_VIA1_A; IDC-Header_2x07_P2.54mm_Vertical; Manufacturer Part 61201421621
J3: HDR_VIA1_B; IDC-Header_2x07_P2.54mm_Vertical; Manufacturer Part 61201421621
JP1: Jumper_2_Open; PinHeader_1x02_P2.54mm_Vertical
L1: 600R; LairdTech_28C0236-0JW-10; Manufacturer Part 28C0236-0JW-10
R1: 1M; R_Axial_DIN0204_L3.6mm_D1.6mm_P5.08mm_Horizontal; Manufacturer Part MBA02040C1004FCT00
R2, R3, R4, R5, R8: 3k3; R_Axial_DIN0204_L3.6mm_D1.6mm_P5.08mm_Horizontal; Manufacturer Part MBA02040C3301FCT00
R6, R7, R9: 1k; R_Axial_DIN0204_L3.6mm_D1.6mm_P5.08mm_Horizontal; Manufacturer Part MBA02040C1001FCT00
R10: 0r002; RESC6430X38N; Manufacturer Part WSLF25122L000FEA
SW1: SW_RES; SW_PUSH_6mm
TP1: CurrentSense; TestPoint_2Pads_Pitch2.54mm_Drill0.8mm
U1: W65C02SxP; DIP-40_W15.24mm_Socket_LongPads; Manufacturer Part W65C02S6TPG-14
U2: HM62256BLP; DIP-28_W15.24mm_Socket_LongPads; Manufacturer Part AS6C62256-55PCN
U3: 28C256; 28655410; Manufacturer Part AT28C256-15PU
U4: W65C22SxP; DIP-40_W15.24mm_Socket_LongPads; Manufacturer Part W65C22S6TPG-14
U5: MCP2221A-I/P; DIP-14_W7.62mm_Socket_LongPads; Manufacturer Part MCP2221A-I/P
U6: W65C51NxP; DIP-28_W15.24mm_Socket_LongPads; Manufacturer Part W65C51N6TPG-14
U7: 74AHC139; DIP-16_W7.62mm_Socket_LongPads; Manufacturer Part SN74AHC139N
U8: DS1813; TO-92; Manufacturer Part DS1813-15+
X1: 1Mhz; Oscillator_DIP-14; Manufacturer Part MXO45T-2C-1M0000
Y1: 1.8432 MHz; Crystal_HC49-U_Vertical; Manufacturer Part AB-1.8432MHZ-B2

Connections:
/A0: U1.9 (A0), U2.10 (A0), U3.10 (A0), U4.38 (RS0), U6.13 (RS0)
/A1: U1.10 (A1), U2.9 (A1), U3.9 (A1), U4.37 (RS1), U6.14 (RS1)
/A2: U1.11 (A2), U2.8 (A2), U3.8 (A2), U4.36 (RS2)
/A3: U1.12 (A3), U2.7 (A3), U3.7 (A3), U4.35 (RS3)
/A4: U1.13 (A4), U2.6 (A4), U3.6 (A4), U4.24 (CS1)
/A5: U1.14 (A5), U2.5 (A5), U3.5 (A5), U6.2 (CS1)
/A6: U1.15 (A6), U2.4 (A6), U3.4 (A6)
/A7: U1.16 (A7), U2.3 (A7), U3.3 (A7)
/A8: U1.17 (A8), U2.25 (A8), U3.25 (A8)
/A9: U1.18 (A9), U2.24 (A9), U3.24 (A9)
/A10: U1.19 (A10), U2.21 (A10), U3.21 (A10)
/A11: U1.20 (A11), U2.23 (A11), U3.23 (A11)
/A12: U1.22 (A12), U2.2 (A12), U3.2 (A12)
/A13: U1.23 (A13), U2.26 (A13), U3.26 (A13)
/A14: U1.24 (A14), U2.1 (A14), U3.1 (A14), U7.2 (A0)
/A15: U1.25 (A15), U2.20 (~CS), U7.3 (A1)
/ACIA_~IRQ: JP1.2 (B), U6.26 (~IRQ)
/BE: R4.2, U1.36 (BE)
/D0: U1.33 (D0), U2.11 (Q0), U3.11 (D0), U4.33 (D0), U6.18 (D0)
/D1: U1.32 (D1), U2.12 (Q1), U3.12 (D1), U4.32 (D1), U6.19 (D1)
/D2: U1.31 (D2), U2.13 (Q2), U3.13 (D2), U4.31 (D2), U6.20 (D2)
/D3: U1.30 (D3), U2.15 (Q3), U3.15 (D3), U4.30 (D3), U6.21 (D3)
/D4: U1.29 (D4), U2.16 (Q4), U3.16 (D4), U4.29 (D4), U6.22 (D4)
/D5: U1.28 (D5), U2.17 (Q5), U3.17 (D5), U4.28 (D5), U6.23 (D5)
/D6: U1.27 (D6), U2.18 (Q6), U3.18 (D6), U4.27 (D6), U6.24 (D6)
/D7: U1.26 (D7), U2.19 (Q7), U3.19 (D7), U4.26 (D7), U6.25 (D7)
/LED_PWR_R: D4.2 (A), R9.2
/LED_RX: D3.1 (K), U5.3 (GP1)
/LED_RX_R: D3.2 (A), R7.2
/LED_TX: D2.1 (K), U5.2 (GP0)
/LED_TX_R: D2.2 (A), R6.2
/PHI2: U1.37 (ϕ0), U4.25 (ϕ2), U6.27 (ϕ2), U7.13 (A1), X1.8 (OUT)
/RDY: R5.2, U1.2 (RDY)
/R/~W: U1.34 (R/~W), U4.22 (R/~W), U6.28 (R/~W), U7.14 (A0)
/S_RXD: U5.6 (UTx), U6.12 (RxD)
/S_TXD: U5.5 (URx), U6.10 (TxD)
/S_XTAL1: C4.1, R1.1, U6.6 (XTAL1), Y1.2
/S_XTAL2: R1.2, U6.7 (XTAL2), Y1.1
/USB_D+: J1.3 (D+), U5.13 (D+)
/USB_D-: J1.2 (D-), U5.12 (D-)
/USB_RST: R8.2, U5.4 (~RST)
/V1A0: J2.3, U4.2 (PA0)
/V1A1: J2.4, U4.3 (PA1)
/V1A2: J2.5, U4.4 (PA2)
/V1A3: J2.6, U4.5 (PA3)
/V1A4: J2.7, U4.6 (PA4)
/V1A5: J2.8, U4.7 (PA5)
/V1A6: J2.9, U4.8 (PA6)
/V1A7: J2.10, U4.9 (PA7)
/V1B0: J3.3, U4.10 (PB0)
/V1B1: J3.4, U4.11 (PB1)
/V1B2: J3.5, U4.12 (PB2)
/V1B3: J3.6, U4.13 (PB3)
/V1B4: J3.7, U4.14 (PB4)
/V1B5: J3.8, U4.15 (PB5)
/V1B6: J3.9, U4.16 (PB6)
/V1B7: J3.10, U4.17 (PB7)
/V1CA1: J2.11, U4.40 (CA1)
/V1CA2: J2.12, U4.39 (CA2)
/V1CB1: J3.11, U4.18 (CB1)
/V1CB2: J3.12, U4.19 (CB2)
/VBUS_SENSE: C6.1, L1.1, R10.2, TP1.2
/VIA_~IRQ: D1.1 (K), U4.21 (~IRQ)
/VUSB: C5.1, U5.11 (VUSB)
/~IO: U4.23 (~CS2), U6.3 (~CS2), U7.5 (O1)
/~IRQ: D1.2 (A), JP1.1 (A), R2.2, U1.4 (~IRQ)
/~NMI: R3.2, U1.6 (~NMI)
/~RD: U2.22 (~OE), U3.22 (~OE), U7.12 (O0)
/~RES: SW1.1, U1.40 (~RES), U4.34 (~RES), U6.4 (~RES), U8.1 (~RST)
/~ROM: U3.20 (~CS), U7.4 (O0)
/~WR: U2.27 (~WE), U7.11 (O1)
GND: C1.2, C2.2, C3.2, C4.2, C5.2, C6.2, C7.2, C8.2, C9.2, C10.2, C11.2, C12.2, C13.2, C14.2, C15.2, C16.1, C18.2, D4.1 (K), J1.4 (GND), J2.2, J2.13, J3.2, J3.13, SW1.2, U1.21 (VSS), U2.14 (GND), U3.14 (GND), U4.1 (VSS), U5.14 (VSS), U6.1 (VSS), U7.1 (E), U7.8 (GND), U7.15 (E), U8.3 (GND), X1.7 (GND)
VBUS: J1.1 (VBUS), R10.1, TP1.1
VCC: C1.1, C2.1, C3.1, C7.1, C8.1, C9.1, C10.1, C11.1, C12.1, C13.1, C14.1, C15.1, C16.2, C18.1, J2.1, J2.14, J3.1, J3.14, L1.2, R2.1, R3.1, R4.1, R5.1, R6.1, R7.1, R8.1, R9.1, U1.8 (VDD), U2.28 (VCC), U3.27 (~WE), U3.28 (VCC), U4.20 (VCC), U5.1 (VDD), U6.15 (VCC), U7.16 (VCC), U8.2 (VCC), X1.14 (Vcc)

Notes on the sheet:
LEDs
System Clock
USB to UART
USB Power Filtering
ROM
Address Decoding Logic
Reset Management
VIA1
RAM

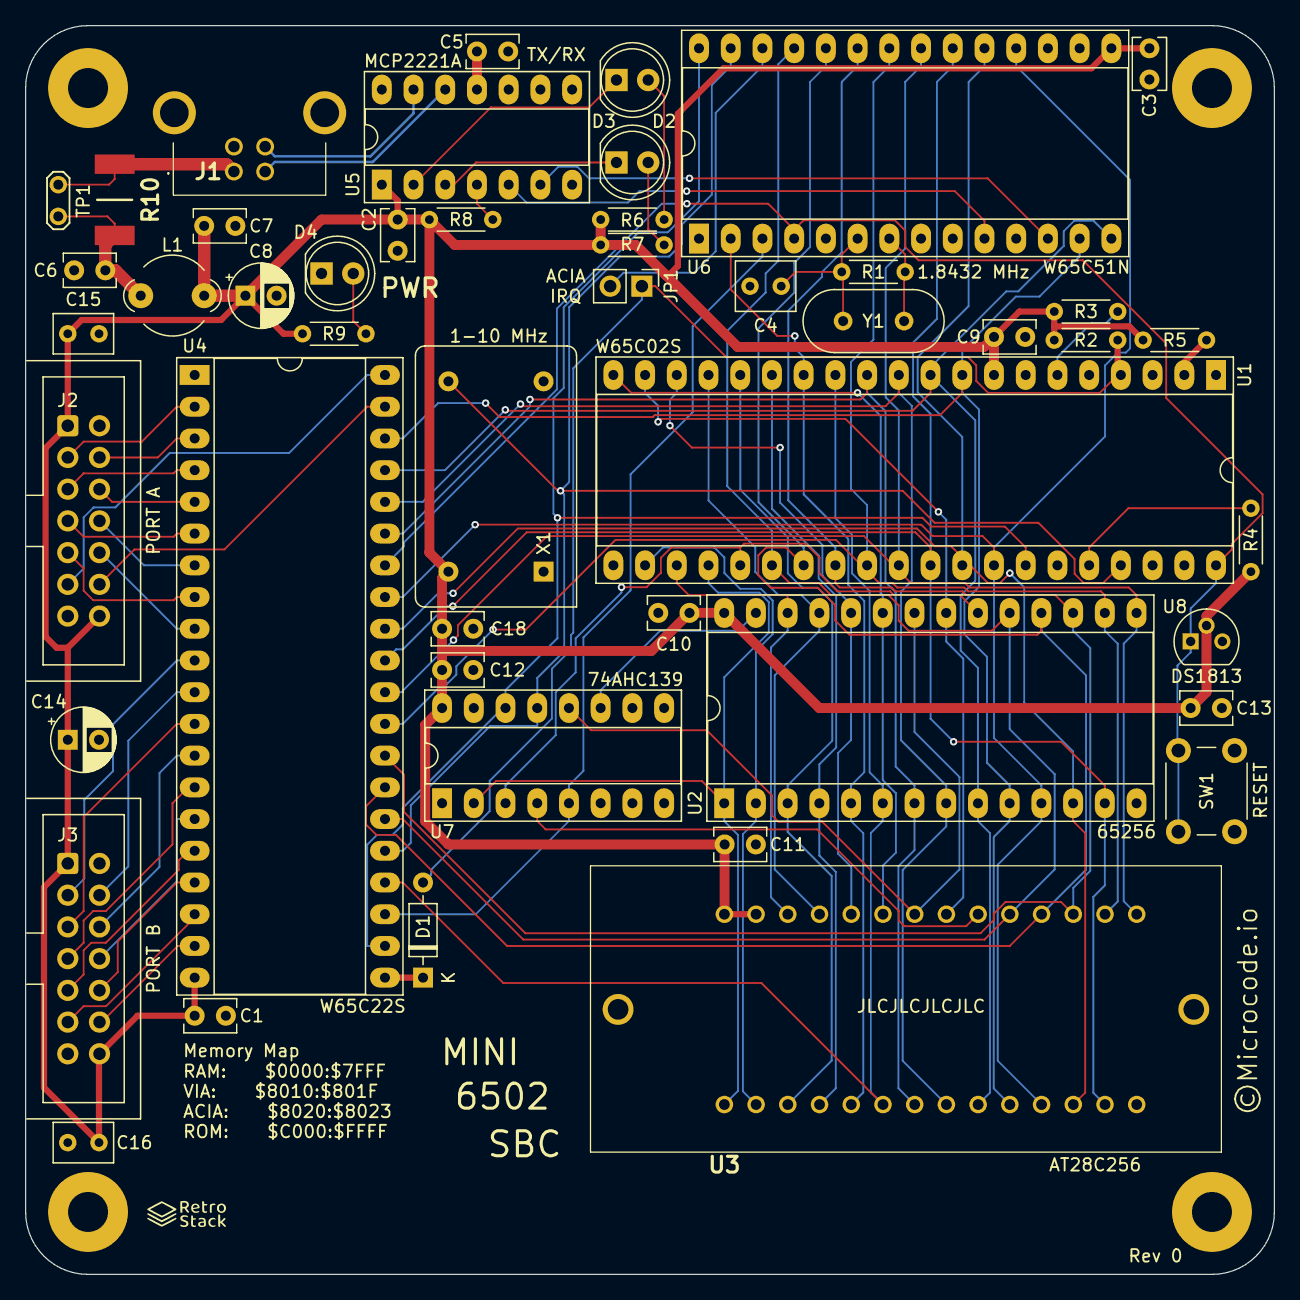
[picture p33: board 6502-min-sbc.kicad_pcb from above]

Board: 4 copper layers, 100.0 x 100.0 mm, 52 parts (0 on the bottom side), 74 nets.

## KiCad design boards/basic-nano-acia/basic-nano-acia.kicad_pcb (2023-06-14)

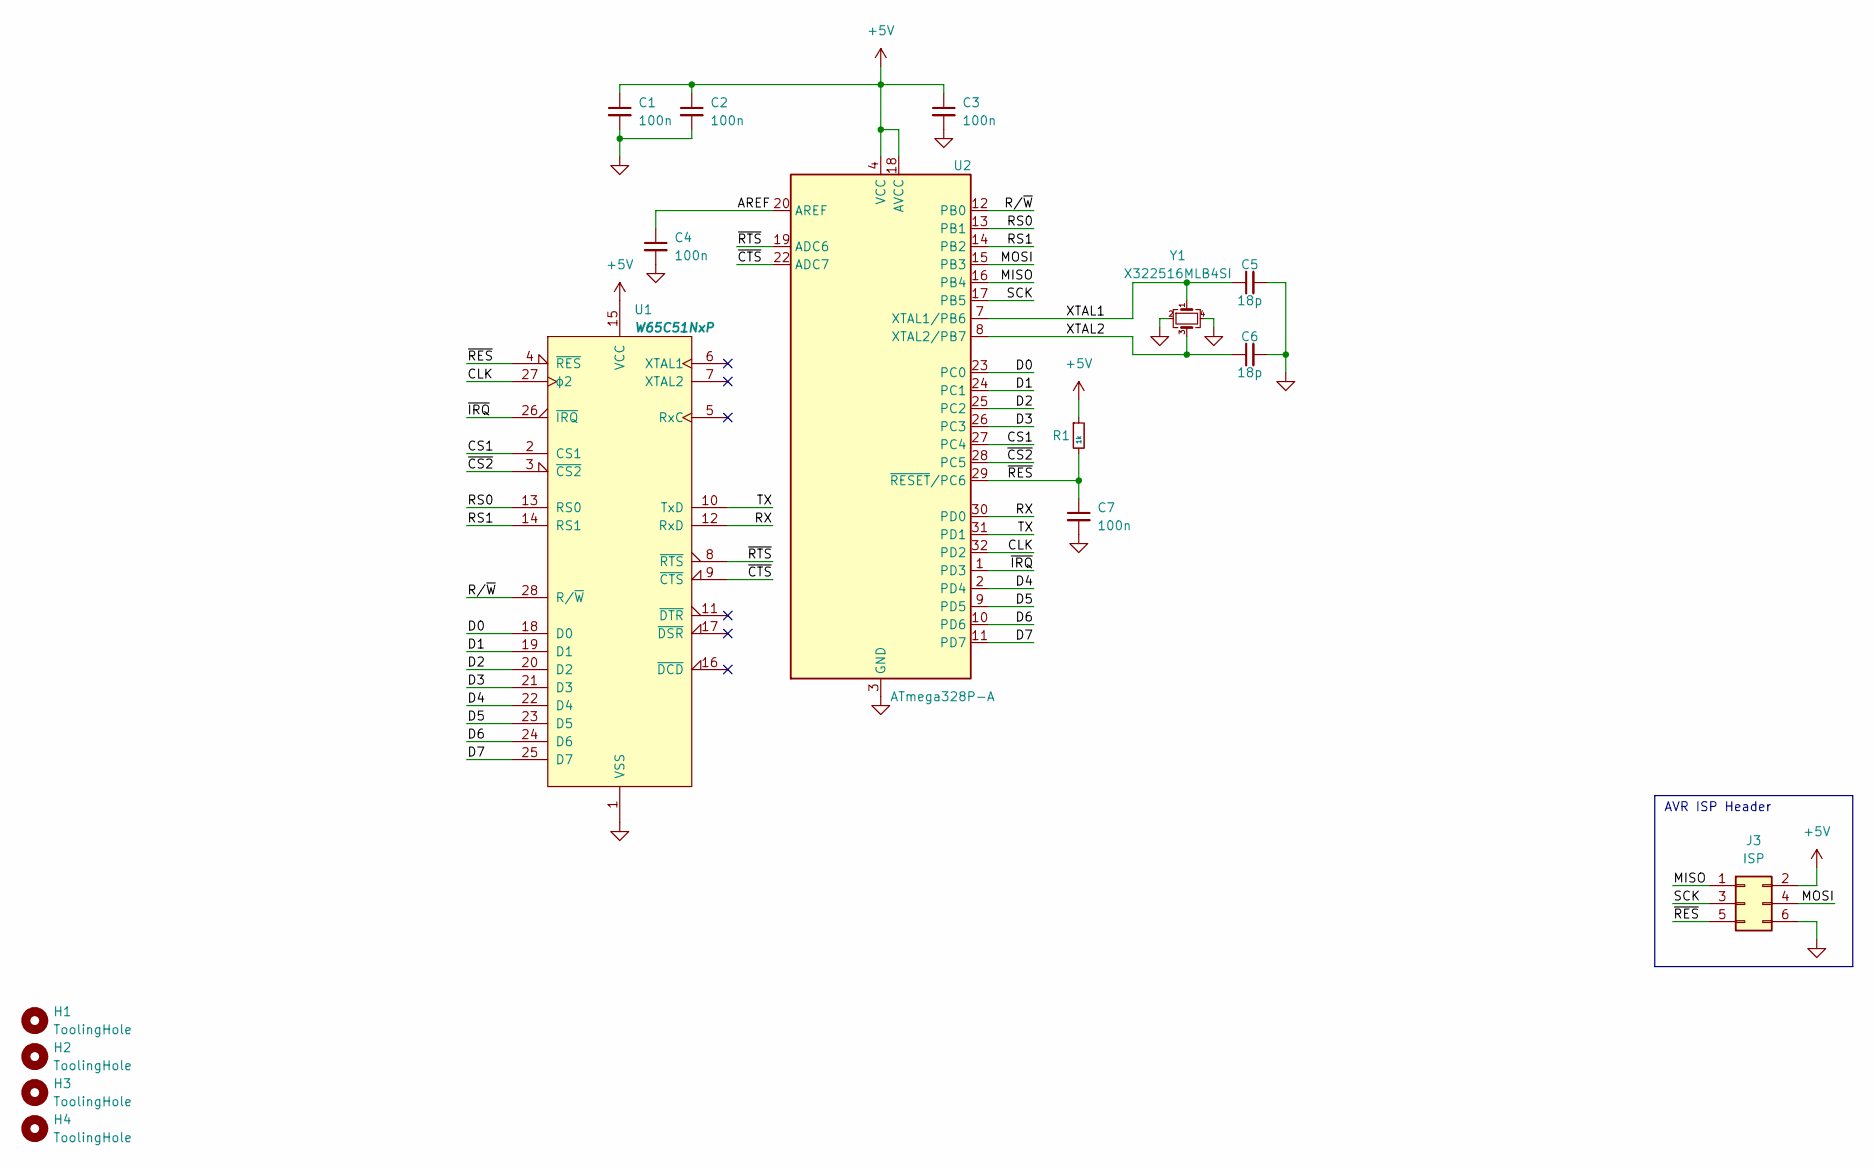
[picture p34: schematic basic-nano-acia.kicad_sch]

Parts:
C1, C2, C3, C4, C7: 100n; C_0402_1005Metric; Mfr Part CL05B104KO5NNNC
C5, C6: 18p; C_0402_1005Metric; Mfr Part 0402CG180J500NT
H1, H2, H3, H4: ToolingHole; ToolingHole_JLCPCB
J3: ISP; PinHeader_2x03_P2.54mm_Vertical
R1: 1k; R_0402_1005Metric; Mfr Part 0402WGF1001TCE
U1: W65C51NxP; DIP-28_W15.24mm
U2: ATmega328P-A; TQFP-32_7x7mm_P0.8mm; Mfr Part ATMEGA328P-AU
Y1: X322516MLB4SI; Crystal_SMD_EuroQuartz_MT-4Pin_3.2x2.5mm; Mfr Part X322516MLB4SI

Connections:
+5V: C1.1, C2.1, C3.1, J3.2, R1.1, U1.15 (VCC), U2.4 (VCC), U2.6 (VCC), U2.18 (AVCC)
/AREF: C4.1, U2.20 (AREF)
/CLK: U1.27 (ϕ2), U2.32 (PD2)
/CS1: U1.2 (CS1), U2.27 (PC4)
/D0: U1.18 (D0), U2.23 (PC0)
/D1: U1.19 (D1), U2.24 (PC1)
/D2: U1.20 (D2), U2.25 (PC2)
/D3: U1.21 (D3), U2.26 (PC3)
/D4: U1.22 (D4), U2.2 (PD4)
/D5: U1.23 (D5), U2.9 (PD5)
/D6: U1.24 (D6), U2.10 (PD6)
/D7: U1.25 (D7), U2.11 (PD7)
/MISO: J3.1, U2.16 (PB4)
/MOSI: J3.4, U2.15 (PB3)
/RS0: U1.13 (RS0), U2.13 (PB1)
/RS1: U1.14 (RS1), U2.14 (PB2)
/RX: U1.12 (RxD), U2.30 (PD0)
/R/~W: U1.28 (R/~W), U2.12 (PB0)
/SCK: J3.3, U2.17 (PB5)
/TX: U1.10 (TxD), U2.31 (PD1)
/XTAL1: C5.1, U2.7 (XTAL1/PB6), Y1.1
/XTAL2: C6.1, U2.8 (XTAL2/PB7), Y1.3
/~CS2: U1.3 (~CS2), U2.28 (PC5)
/~CTS: U1.9 (~CTS), U2.22 (ADC7)
/~IRQ: U1.26 (~IRQ), U2.1 (PD3)
/~RES: C7.1, J3.5, R1.2, U1.4 (~RES), U2.29 (~RESET/PC6)
/~RTS: U1.8 (~RTS), U2.19 (ADC6)
GND: C1.2, C2.2, C3.2, C4.2, C5.2, C6.2, C7.2, J3.6, U1.1 (VSS), U2.3 (GND), U2.5 (GND), U2.21 (GND), Y1.2, Y1.4

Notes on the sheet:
AVR ISP Header

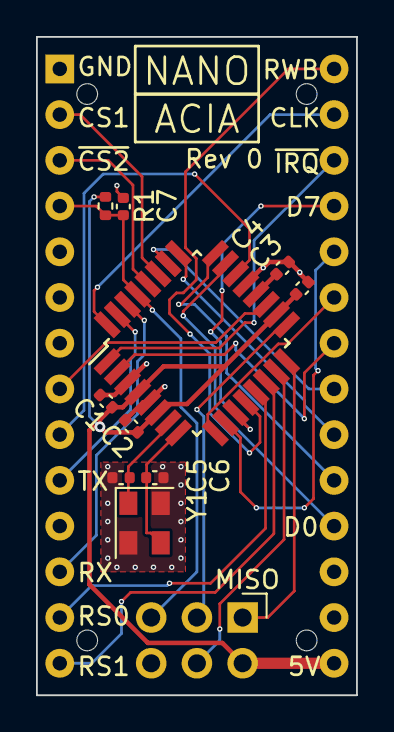
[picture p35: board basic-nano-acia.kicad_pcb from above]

Board: 4 copper layers, 17.8 x 36.6 mm, 16 parts (0 on the bottom side), 28 nets.

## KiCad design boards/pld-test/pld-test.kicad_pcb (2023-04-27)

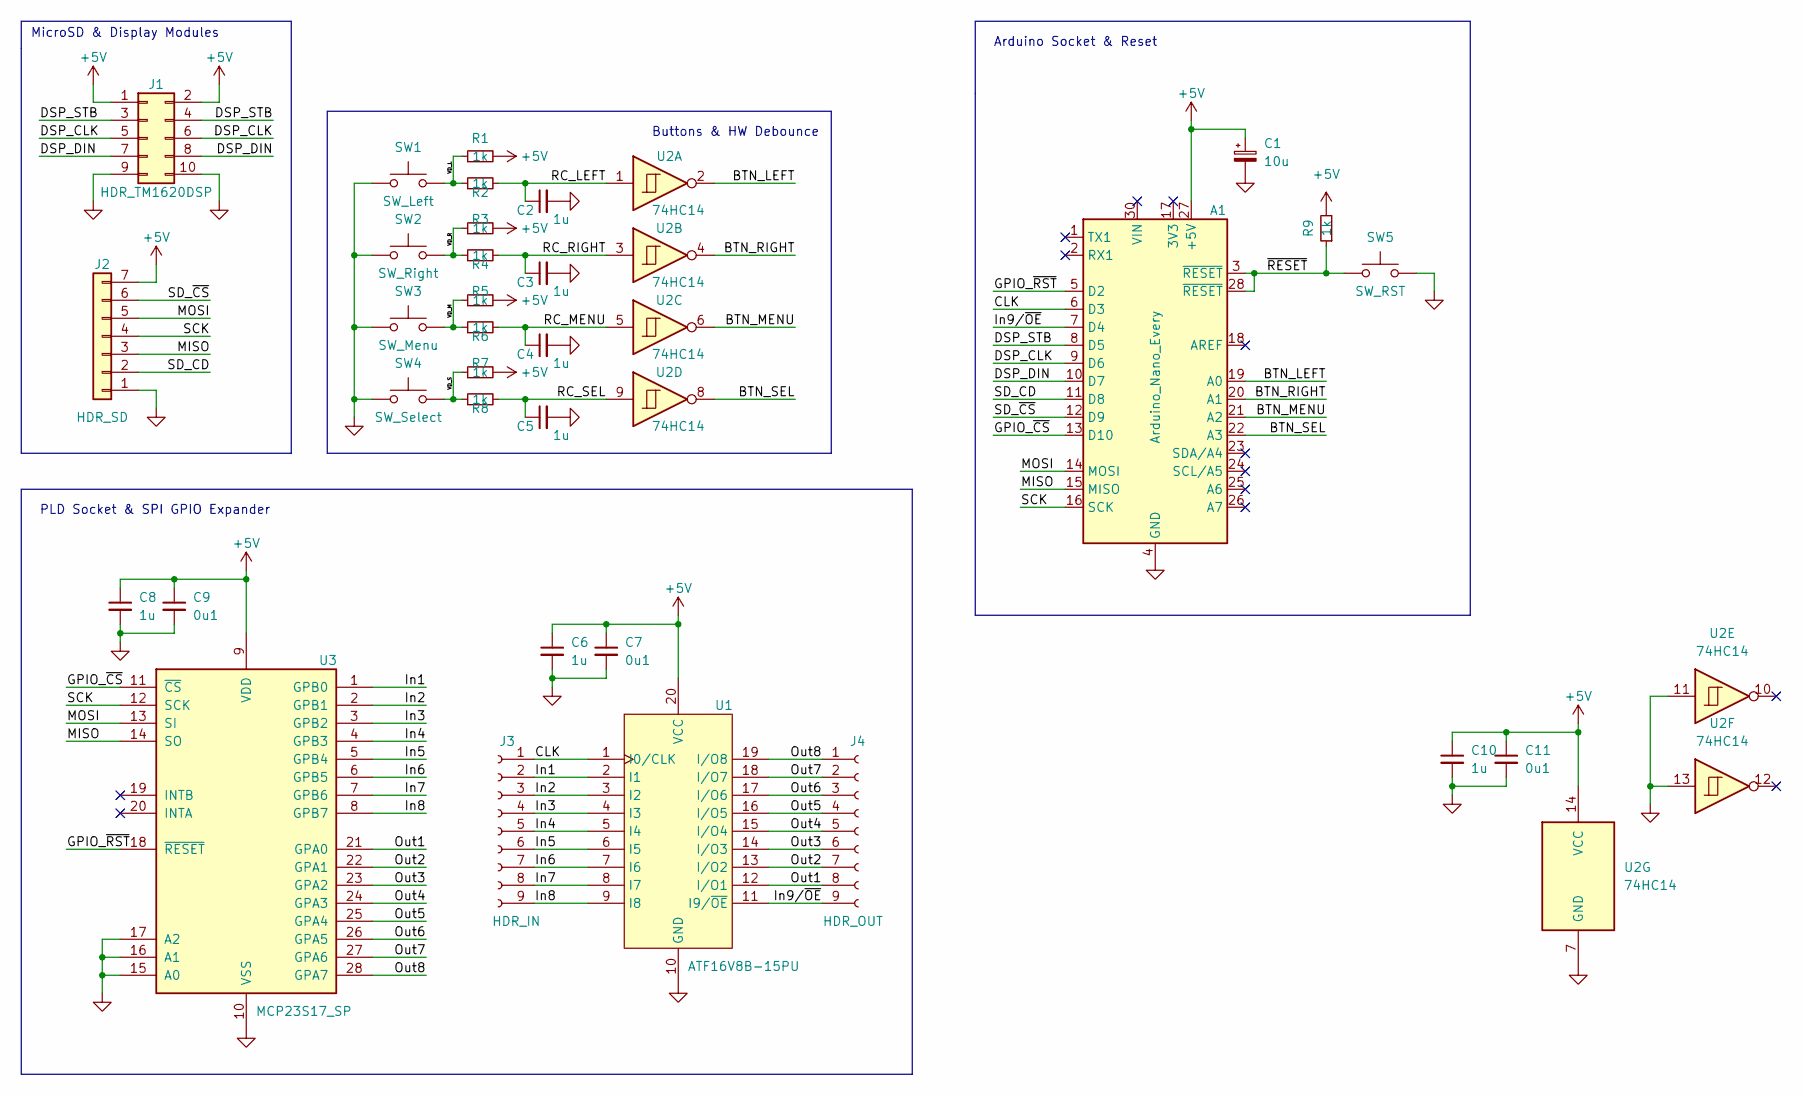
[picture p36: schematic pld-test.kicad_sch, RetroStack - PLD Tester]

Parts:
A1: Arduino_Nano_Every; Arduino_Nano; Man Part # ABX00028
C1: 10u; CP_Radial_D5.0mm_P2.50mm; Man Part # ECE-A1EKS100I
C2, C3, C4, C5, C6, C8, C10: 1u; C_Rect_L4.0mm_W2.5mm_P2.50mm; Man Part # FA18X7R1E105KRU06
C7, C9, C11: 0u1; C_Rect_L4.0mm_W2.5mm_P2.50mm; Man Part # K104K15X7RF5TL2
J1: HDR_TM1620DSP; PinHeader_2x05_P2.54mm_Vertical
J2: HDR_SD; PinHeader_1x07_P2.54mm_Vertical; Man Part # DEV-13743
J3: HDR_IN; PinSocket_1x09_P2.54mm_Vertical; Man Part # 310-87-109-41-001101
J4: HDR_OUT; PinSocket_1x09_P2.54mm_Vertical; Man Part # 310-87-109-41-001101
R1, R2, R3, R4, R5, R6, R7, R8, R9: 1k; R_Axial_DIN0204_L3.6mm_D1.6mm_P5.08mm_Horizontal; Man Part # MBA02040C1001FCT00
SW1: SW_Left; SW_PUSH_6mm; Man Part # TS02-66-43-BK-260-LCR-D
SW2: SW_Right; SW_PUSH_6mm; Man Part # TS02-66-43-BK-260-LCR-D
SW3: SW_Menu; SW_PUSH_6mm; Man Part # TS02-66-43-BK-260-LCR-D
SW4: SW_Select; SW_PUSH_6mm; Man Part # TS02-66-43-BK-260-LCR-D
SW5: SW_RST; SW_PUSH_6mm; Man Part # TS02-66-43-BK-260-LCR-D
U1: ATF16V8B-15PU; DIP-20_W7.62mm_Socket_LongPads; Man Part # ATF16V8B-15PU
U2: 74HC14; DIP-14_W7.62mm_Socket_LongPads; Man Part # SN74HC14N
U3: MCP23S17_SP; DIP-28_W7.62mm_Socket_LongPads; Man Part # MCP23S17-E/SP

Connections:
+5V: A1.27 (+5V), C1.1, C6.1, C7.1, C8.1, C9.1, C10.1, C11.1, J1.1, J1.2, J2.7, R1.2, R3.2, R5.2, R7.2, R9.2, U1.20 (VCC), U2.14 (VCC), U3.9 (VDD)
/BTN_LEFT: A1.19 (A0), U2.2
/BTN_MENU: A1.21 (A2), U2.6
/BTN_RIGHT: A1.20 (A1), U2.4
/BTN_SEL: A1.22 (A3), U2.8
/CLK: A1.6 (D3), J3.1, U1.1 (I0/CLK)
/DSP_CLK: A1.9 (D6), J1.5, J1.6
/DSP_DIN: A1.10 (D7), J1.7, J1.8
/DSP_STB: A1.8 (D5), J1.3, J1.4
/GPIO_~CS: A1.13 (D10), U3.11 (~CS)
/GPIO_~RST: A1.5 (D2), U3.18 (~RESET)
/In1: J3.2, U1.2 (I1), U3.1 (GPB0)
/In2: J3.3, U1.3 (I2), U3.2 (GPB1)
/In3: J3.4, U1.4 (I3), U3.3 (GPB2)
/In4: J3.5, U1.5 (I4), U3.4 (GPB3)
/In5: J3.6, U1.6 (I5), U3.5 (GPB4)
/In6: J3.7, U1.7 (I6), U3.6 (GPB5)
/In7: J3.8, U1.8 (I7), U3.7 (GPB6)
/In8: J3.9, U1.9 (I8), U3.8 (GPB7)
/In9/~OE: A1.7 (D4), J4.9, U1.11 (I9/~OE)
/MISO: A1.15 (MISO), J2.3, U3.14 (SO)
/MOSI: A1.14 (MOSI), J2.5, U3.13 (SI)
/Out1: J4.8, U1.12 (I/O1), U3.21 (GPA0)
/Out2: J4.7, U1.13 (I/O2), U3.22 (GPA1)
/Out3: J4.6, U1.14 (I/O3), U3.23 (GPA2)
/Out4: J4.5, U1.15 (I/O4), U3.24 (GPA3)
/Out5: J4.4, U1.16 (I/O5), U3.25 (GPA4)
/Out6: J4.3, U1.17 (I/O6), U3.26 (GPA5)
/Out7: J4.2, U1.18 (I/O7), U3.27 (GPA6)
/Out8: J4.1, U1.19 (I/O8), U3.28 (GPA7)
/RC_LEFT: C2.1, R2.2, U2.1
/RC_MENU: C4.1, R6.2, U2.5
/RC_RIGHT: C3.1, R4.2, U2.3
/RC_SEL: C5.1, R8.2, U2.9
/SCK: A1.16 (SCK), J2.4, U3.12 (SCK)
/SD_CD: A1.11 (D8), J2.2
/SD_~CS: A1.12 (D9), J2.6
/VD_L: R1.1, R2.1, SW1.2
/VD_M: R5.1, R6.1, SW3.2
/VD_R: R3.1, R4.1, SW2.2
/VD_S: R7.1, R8.1, SW4.2
/~RESET: A1.3 (~RESET), A1.28 (~RESET), R9.1, SW5.1
GND: A1.4 (GND), A1.29 (GND), C1.2, C2.2, C3.2, C4.2, C5.2, C6.2, C7.2, C8.2, C9.2, C10.2, C11.2, J1.9, J1.10, J2.1, SW1.1, SW2.1, SW3.1, SW4.1, SW5.2, U1.10 (GND), U2.7 (GND), U2.11, U2.13, U3.10 (VSS), U3.15 (A0), U3.16 (A1), U3.17 (A2)

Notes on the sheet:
MicroSD & Display Modules
Buttons & HW Debounce
Arduino Socket & Reset
PLD Socket & SPI GPIO Expander

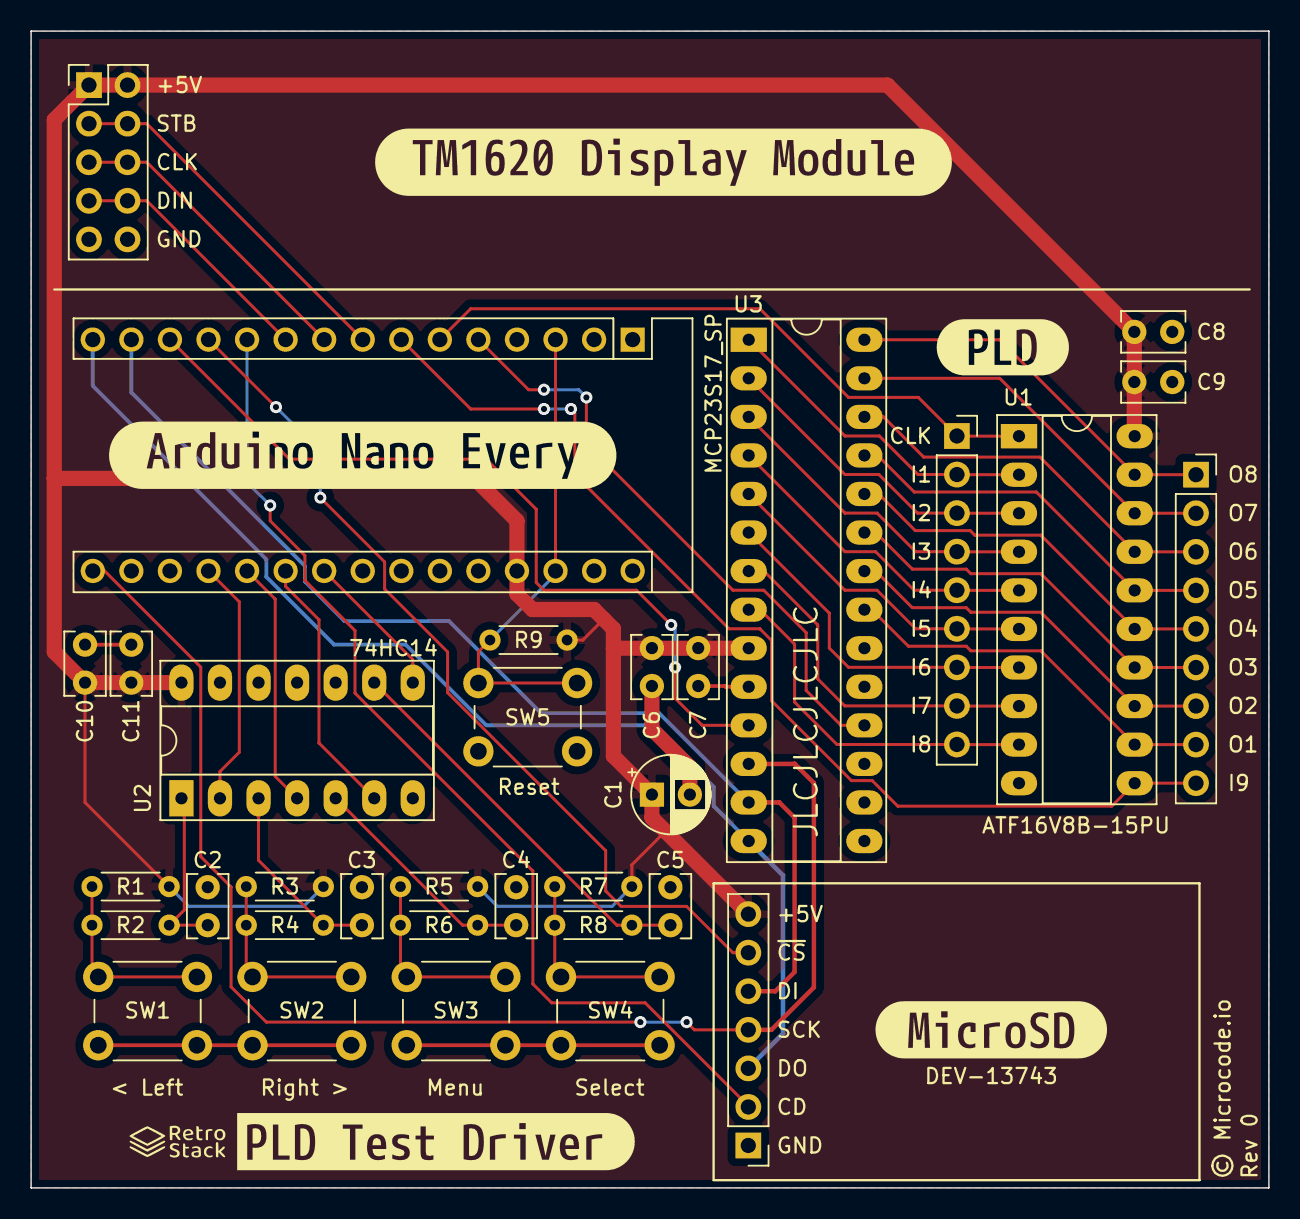
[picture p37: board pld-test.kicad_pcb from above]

Board: 2 copper layers, 81.5 x 76.2 mm, 38 parts (0 on the bottom side), 43 nets.

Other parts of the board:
kibuzzard-644A8BCE: G***; kibuzzard-644A8BCE
kibuzzard-644A90FB: G***; kibuzzard-644A90FB
kibuzzard-644A91A0: G***; kibuzzard-644A91A0
kibuzzard-644A909B: G***; kibuzzard-644A909B
kibuzzard-644AA1EA: G***; kibuzzard-644AA1EA

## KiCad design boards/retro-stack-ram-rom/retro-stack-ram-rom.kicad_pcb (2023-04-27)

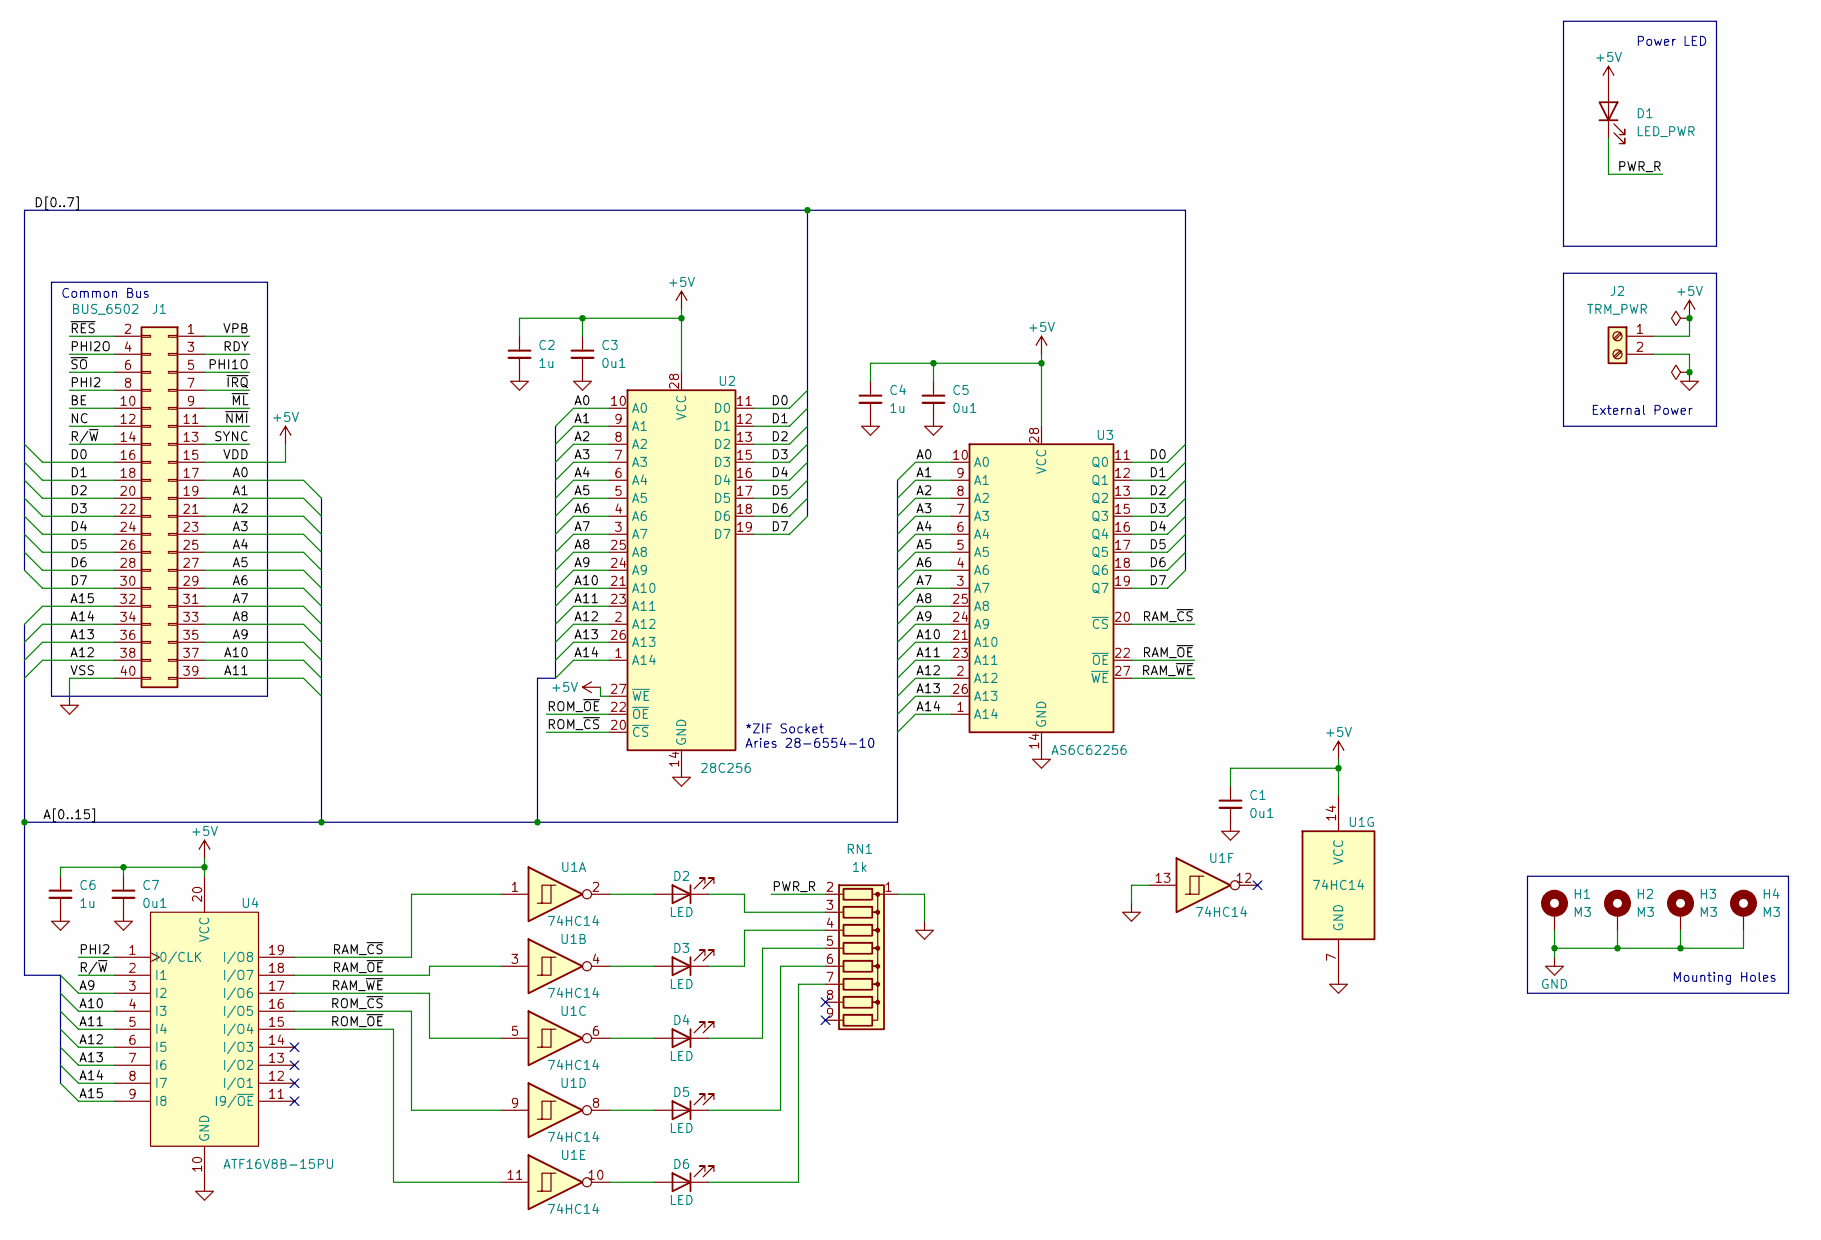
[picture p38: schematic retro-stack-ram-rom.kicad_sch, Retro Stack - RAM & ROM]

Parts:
C1, C3, C5, C7: 0u1; C_Rect_L4.0mm_W2.5mm_P2.50mm; Mfr Part RCER71E104K0A2H03B
C2, C4, C6: 1u; C_Rect_L4.0mm_W2.5mm_P2.50mm; Mfr Part FA18X7R1E105KRU06
D1: LED_PWR; LED_D5.0mm
D2, D3, D4, D5, D6: LED; LED_D5.0mm
H1, H2, H3, H4: M3; MountingHole_3.2mm_M3_ISO7380_Pad
J1: BUS_6502; IDC-Header_2x20_P2.54mm_Horizontal; Mfr Part 1979
J2: TRM_PWR; TerminalBlock_Phoenix_MPT-0,5-2-2.54_1x02_P2.54mm_Horizontal; Mfr Part 1725656
RN1: 1k; R_Array_SIP9
U1: 74HC14; DIP-14_W7.62mm_Socket_LongPads
U2: 28C256; 28655410; Mfr Part 28-526-10
U3: AS6C62256; DIP-28_W15.24mm_Socket_LongPads; Mfr Part AS6C62256-55PCN
U4: ATF16V8B-15PU; DIP-20_W7.62mm_Socket_LongPads; Mfr Part ATF16V8B-15PU

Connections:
+5V: C1.1, C2.1, C3.1, C4.1, C5.1, C6.1, C7.1, D1.2 (A), J1.15, J2.1, U1.14 (VCC), U2.27 (~WE), U2.28 (VCC), U3.28 (VCC), U4.20 (VCC)
/A0: J1.17, U2.10 (A0), U3.10 (A0)
/A1: J1.19, U2.9 (A1), U3.9 (A1)
/A2: J1.21, U2.8 (A2), U3.8 (A2)
/A3: J1.23, U2.7 (A3), U3.7 (A3)
/A4: J1.25, U2.6 (A4), U3.6 (A4)
/A5: J1.27, U2.5 (A5), U3.5 (A5)
/A6: J1.29, U2.4 (A6), U3.4 (A6)
/A7: J1.31, U2.3 (A7), U3.3 (A7)
/A8: J1.33, U2.25 (A8), U3.25 (A8)
/A9: J1.35, U2.24 (A9), U3.24 (A9), U4.3 (I2)
/A10: J1.37, U2.21 (A10), U3.21 (A10), U4.4 (I3)
/A11: J1.39, U2.23 (A11), U3.23 (A11), U4.5 (I4)
/A12: J1.38, U2.2 (A12), U3.2 (A12), U4.6 (I5)
/A13: J1.36, U2.26 (A13), U3.26 (A13), U4.7 (I6)
/A14: J1.34, U2.1 (A14), U3.1 (A14), U4.8 (I7)
/A15: J1.32, U4.9 (I8)
/BE: J1.10
/D0: J1.16, U2.11 (D0), U3.11 (Q0)
/D1: J1.18, U2.12 (D1), U3.12 (Q1)
/D2: J1.20, U2.13 (D2), U3.13 (Q2)
/D3: J1.22, U2.15 (D3), U3.15 (Q3)
/D4: J1.24, U2.16 (D4), U3.16 (Q4)
/D5: J1.26, U2.17 (D5), U3.17 (Q5)
/D6: J1.28, U2.18 (D6), U3.18 (Q6)
/D7: J1.30, U2.19 (D7), U3.19 (Q7)
/NC: J1.12
/PHI1O: J1.5
/PHI2: J1.8, U4.1 (I0/CLK)
/PHI2O: J1.4
/PWR_R: D1.1 (K), RN1.2 (R1)
/RAM_~CS: U1.1, U3.20 (~CS), U4.19 (I/O8)
/RAM_~OE: U1.3, U3.22 (~OE), U4.18 (I/O7)
/RAM_~WE: U1.5, U3.27 (~WE), U4.17 (I/O6)
/RDY: J1.3
/ROM_~CS: U1.9, U2.20 (~CS), U4.16 (I/O5)
/ROM_~OE: U1.11, U2.22 (~OE), U4.15 (I/O4)
/R/~W: J1.14, U4.2 (I1)
/SYNC: J1.13
/VPB: J1.1
/~IRQ: J1.7
/~ML: J1.9
/~NMI: J1.11
/~RES: J1.2
/~SO: J1.6
GND: C1.2, C2.2, C3.2, C4.2, C5.2, C6.2, C7.2, H1.1, H2.1, H3.1, H4.1, J1.40, J2.2, RN1.1 (common), U1.7 (GND), U1.13, U2.14 (GND), U3.14 (GND), U4.10 (GND)
unnamed: D2.2 (A), U1.2
unnamed: D3.2 (A), U1.4
unnamed: D4.2 (A), U1.6
unnamed: D5.2 (A), U1.8
unnamed: D6.2 (A), U1.10
unnamed: D2.1 (K), RN1.3 (R2)
unnamed: D3.1 (K), RN1.4 (R3)
unnamed: D4.1 (K), RN1.5 (R4)
unnamed: D5.1 (K), RN1.6 (R5)
unnamed: D6.1 (K), RN1.7 (R6)

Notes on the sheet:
Power LED
External Power
*ZIF Socket Aries 28-6554-10
Common Bus
Mounting Holes

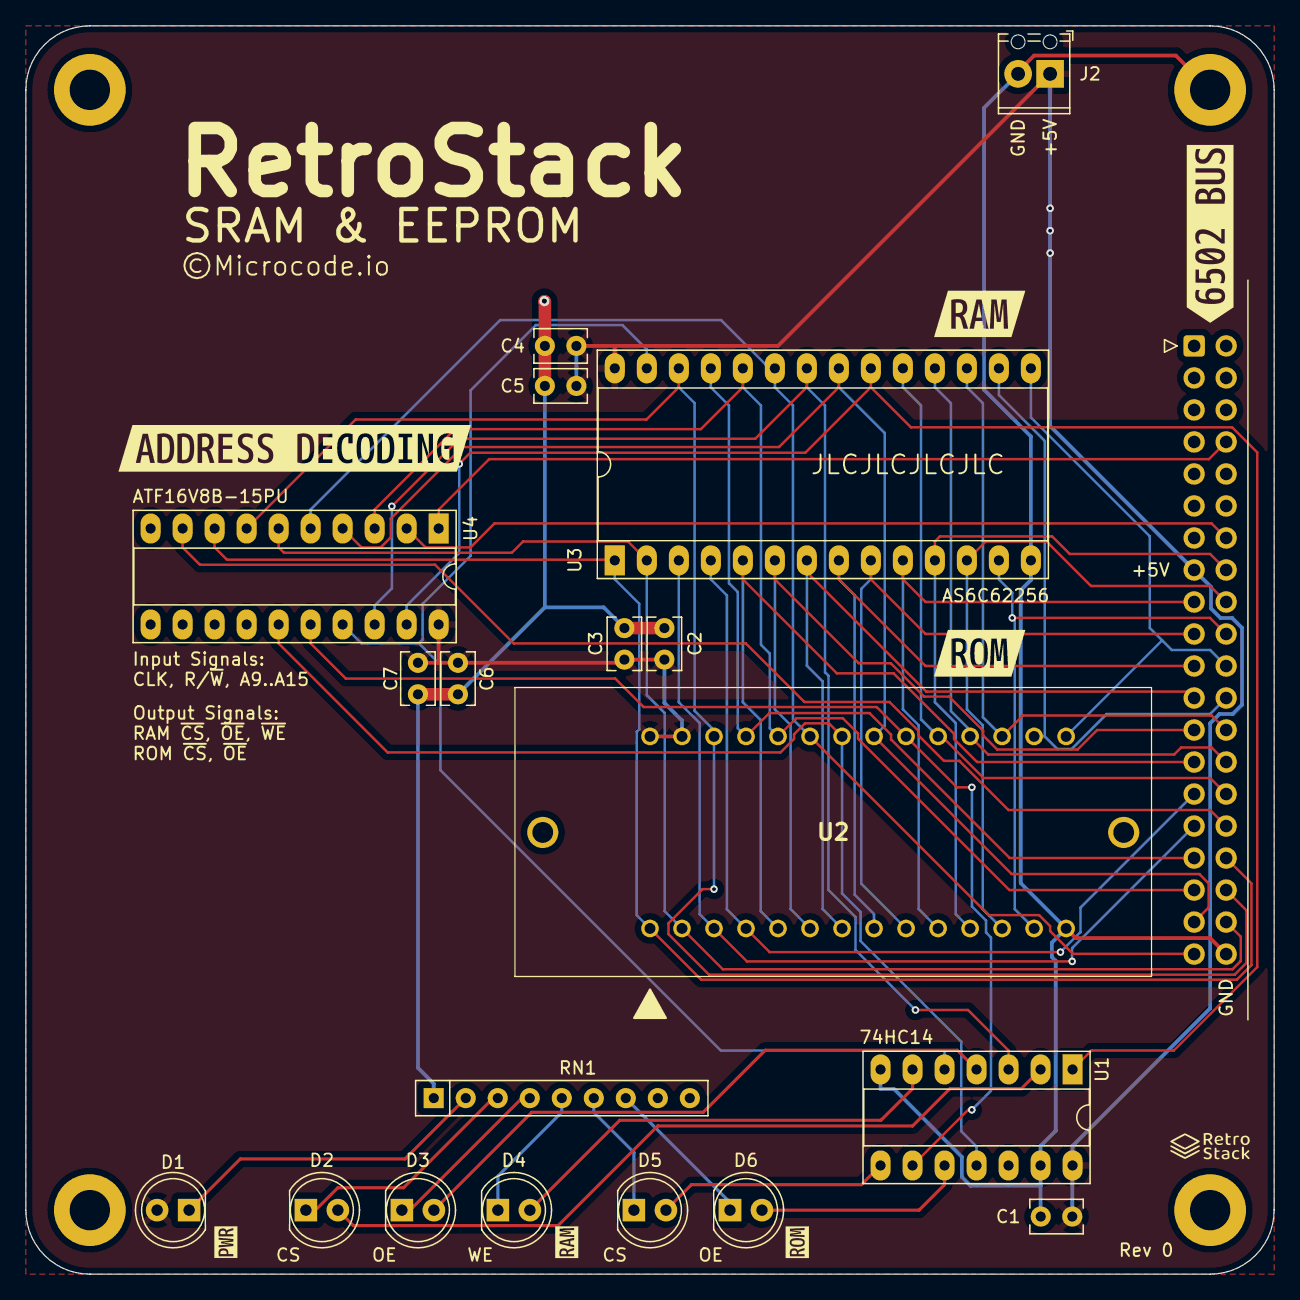
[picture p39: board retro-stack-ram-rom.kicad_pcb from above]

Board: 2 copper layers, 99.1 x 99.1 mm, 31 parts (0 on the bottom side), 44 nets.

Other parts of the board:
kibuzzard-642C367F: G***; kibuzzard-642C367F
kibuzzard-642DBD4D: G***; kibuzzard-642DBD4D
kibuzzard-642DBD42: G***; kibuzzard-642DBD42
kibuzzard-642DC482: G***; kibuzzard-642DC482
kibuzzard-642888DE: G***; kibuzzard-642888DE
kibuzzard-6448402D: G***; kibuzzard-6448402D
kibuzzard-64484043: G***; kibuzzard-64484043

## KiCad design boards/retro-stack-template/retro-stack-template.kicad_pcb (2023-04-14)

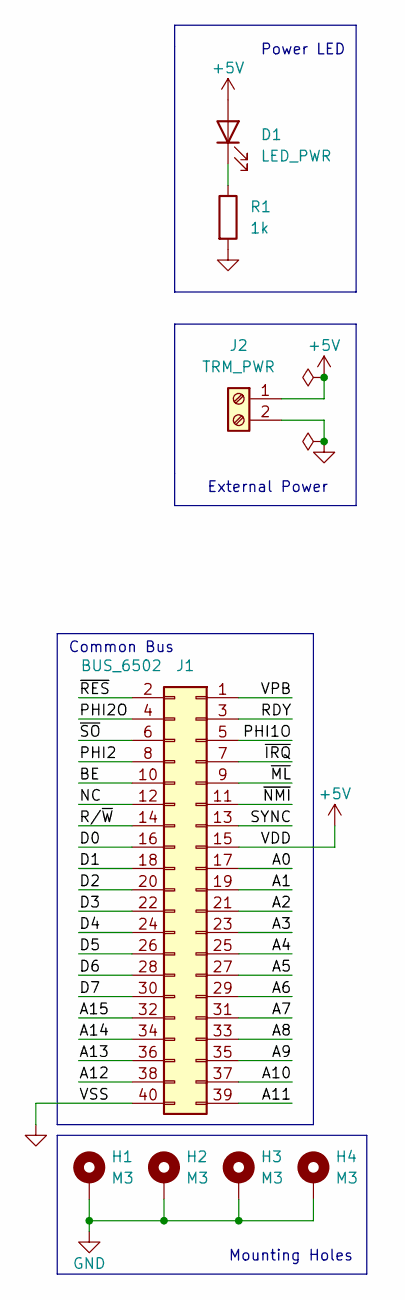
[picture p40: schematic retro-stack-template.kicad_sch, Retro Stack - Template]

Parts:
D1: LED_PWR; LED_D5.0mm
H1, H2, H3, H4: M3; MountingHole_3.2mm_M3_ISO7380_Pad
J1: BUS_6502; IDC-Header_2x20_P2.54mm_Horizontal
J2: TRM_PWR; TerminalBlock_Phoenix_MPT-0,5-2-2.54_1x02_P2.54mm_Horizontal; Mfr Part 1725656
R1: 1k; R_Axial_DIN0204_L3.6mm_D1.6mm_P5.08mm_Horizontal

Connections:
+5V: D1.2 (A), J1.15, J2.1
/A0: J1.17
/A1: J1.19
/A2: J1.21
/A3: J1.23
/A4: J1.25
/A5: J1.27
/A6: J1.29
/A7: J1.31
/A8: J1.33
/A9: J1.35
/A10: J1.37
/A11: J1.39
/A12: J1.38
/A13: J1.36
/A14: J1.34
/A15: J1.32
/BE: J1.10
/D0: J1.16
/D1: J1.18
/D2: J1.20
/D3: J1.22
/D4: J1.24
/D5: J1.26
/D6: J1.28
/D7: J1.30
/NC: J1.12
/PHI1O: J1.5
/PHI2: J1.8
/PHI2O: J1.4
/RDY: J1.3
/R/~W: J1.14
/SYNC: J1.13
/VPB: J1.1
/~IRQ: J1.7
/~ML: J1.9
/~NMI: J1.11
/~RES: J1.2
/~SO: J1.6
GND: H1.1, H2.1, H3.1, H4.1, J1.40, J2.2, R1.2
unnamed: D1.1 (K), R1.1

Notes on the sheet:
External Power
Common Bus
Power LED
Mounting Holes

Board: 2 copper layers, 11 parts (0 on the bottom side), 3 nets, no tracks yet.

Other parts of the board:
kibuzzard-642C36EF: G***; kibuzzard-642C36EF
kibuzzard-642C367F: G***; kibuzzard-642C367F
kibuzzard-642888DE: G***; kibuzzard-642888DE

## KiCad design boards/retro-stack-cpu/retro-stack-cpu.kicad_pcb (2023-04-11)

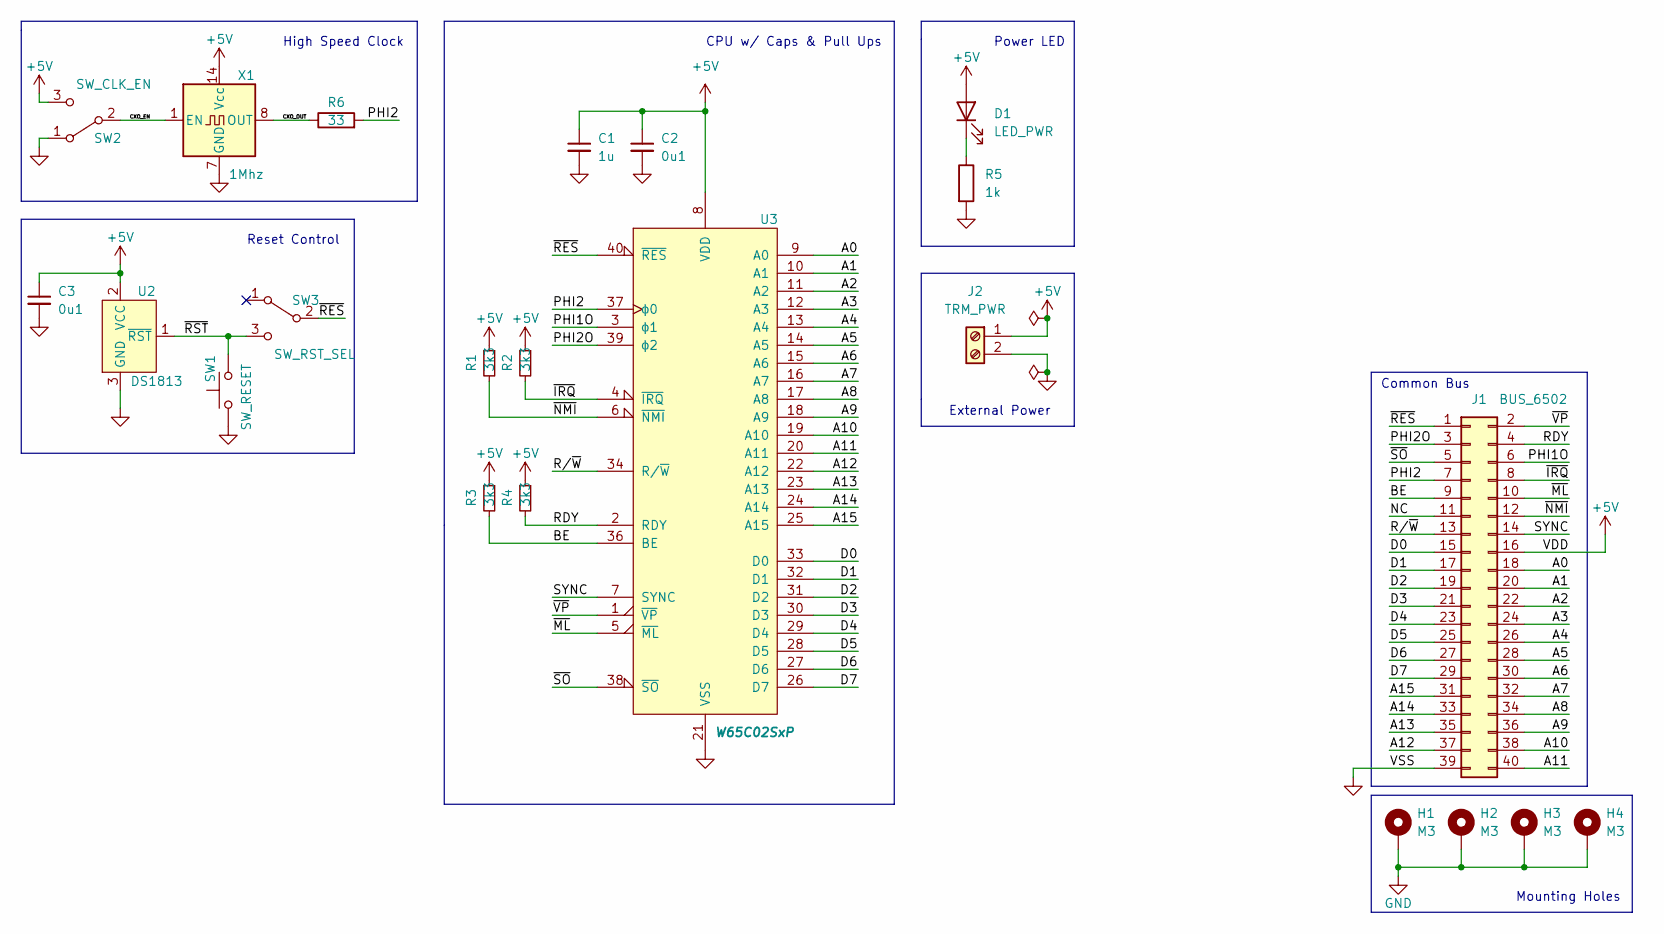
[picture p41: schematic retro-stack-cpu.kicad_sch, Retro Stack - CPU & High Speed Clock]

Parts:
C1: 1u; C_Rect_L4.0mm_W2.5mm_P2.50mm; Mfr Part FA18X7R1E105KRU06
C2, C3: 0u1; C_Rect_L4.0mm_W2.5mm_P2.50mm; Mfr Part RCER71E104K0A2H03B
D1: LED_PWR; LED_D5.0mm
H1, H2, H3, H4: M3; MountingHole_3.2mm_M3_ISO7380_Pad
J1: BUS_6502; PinSocket_2x20_P2.54mm_Vertical; Mfr Part 1979
J2: TRM_PWR; TerminalBlock_Phoenix_MPT-0,5-2-2.54_1x02_P2.54mm_Horizontal; Mfr Part 1725656
R1, R2, R3, R4: 3k3; R_Axial_DIN0204_L3.6mm_D1.6mm_P5.08mm_Horizontal; Mfr Part MBA02040C3301FRP00
R5: 1k; R_Axial_DIN0204_L3.6mm_D1.6mm_P5.08mm_Horizontal; Mfr Part MBA02040C1001FCT00
R6: 33; R_Axial_DIN0204_L3.6mm_D1.6mm_P5.08mm_Horizontal; Mfr Part MBA02040C3309FC100
SW1: SW_RESET; SW_Tactile_SPST_Angled_PTS645Vx58-2LFS; Mfr Part TS11-674-73-BK-100-RA-D
SW2: SW_CLK_EN; LC1258EENP1RLGR; Mfr Part LC1258EENP1RLGR
SW3: SW_RST_SEL; LC1258EENP1RLGR; Mfr Part LC1258EENP1RLGR
U2: DS1813; TO-92; Mfr Part DS1813-10+T&R
U3: W65C02SxP; DIP-40_W15.24mm_Socket_LongPads; Mfr Part W65C02S6TPG-14
X1: 1Mhz; Oscillator_DIP-14; Mfr Part MXO45T-2C-1M0000

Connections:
+5V: C1.1, C2.1, C3.1, D1.2 (A), J1.16, J2.1, R1.1, R2.1, R3.1, R4.1, SW2.3 (C), U2.2 (VCC), U3.8 (VDD), X1.14 (Vcc)
/A0: J1.18, U3.9 (A0)
/A1: J1.20, U3.10 (A1)
/A2: J1.22, U3.11 (A2)
/A3: J1.24, U3.12 (A3)
/A4: J1.26, U3.13 (A4)
/A5: J1.28, U3.14 (A5)
/A6: J1.30, U3.15 (A6)
/A7: J1.32, U3.16 (A7)
/A8: J1.34, U3.17 (A8)
/A9: J1.36, U3.18 (A9)
/A10: J1.38, U3.19 (A10)
/A11: J1.40, U3.20 (A11)
/A12: J1.37, U3.22 (A12)
/A13: J1.35, U3.23 (A13)
/A14: J1.33, U3.24 (A14)
/A15: J1.31, U3.25 (A15)
/BE: J1.9, R3.2, U3.36 (BE)
/CXO_EN: SW2.2 (B), X1.1 (EN)
/CXO_OUT: R6.1, X1.8 (OUT)
/D0: J1.15, U3.33 (D0)
/D1: J1.17, U3.32 (D1)
/D2: J1.19, U3.31 (D2)
/D3: J1.21, U3.30 (D3)
/D4: J1.23, U3.29 (D4)
/D5: J1.25, U3.28 (D5)
/D6: J1.27, U3.27 (D6)
/D7: J1.29, U3.26 (D7)
/NC: J1.11
/PHI1O: J1.6, U3.3 (ϕ1)
/PHI2: J1.7, R6.2, U3.37 (ϕ0)
/PHI2O: J1.3, U3.39 (ϕ2)
/RDY: J1.4, R4.2, U3.2 (RDY)
/R/~W: J1.13, U3.34 (R/~W)
/SYNC: J1.14, U3.7 (SYNC)
/~IRQ: J1.8, R2.2, U3.4 (~IRQ)
/~ML: J1.10, U3.5 (~ML)
/~NMI: J1.12, R1.2, U3.6 (~NMI)
/~RES: J1.1, SW3.2 (B), U3.40 (~RES)
/~RST: SW1.2, SW3.3 (C), U2.1 (~RST)
/~SO: J1.5, U3.38 (~SO)
/~VP: J1.2, U3.1 (~VP)
GND: C1.2, C2.2, C3.2, H1.1, H2.1, H3.1, H4.1, J1.39, J2.2, R5.2, SW1.1, SW2.1 (A), U2.3 (GND), U3.21 (VSS), X1.7 (GND)
unnamed: D1.1 (K), R5.1

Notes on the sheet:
CPU w/ Caps & Pull Ups
Common Bus
Power LED
High Speed Clock
External Power
Reset Control
Mounting Holes

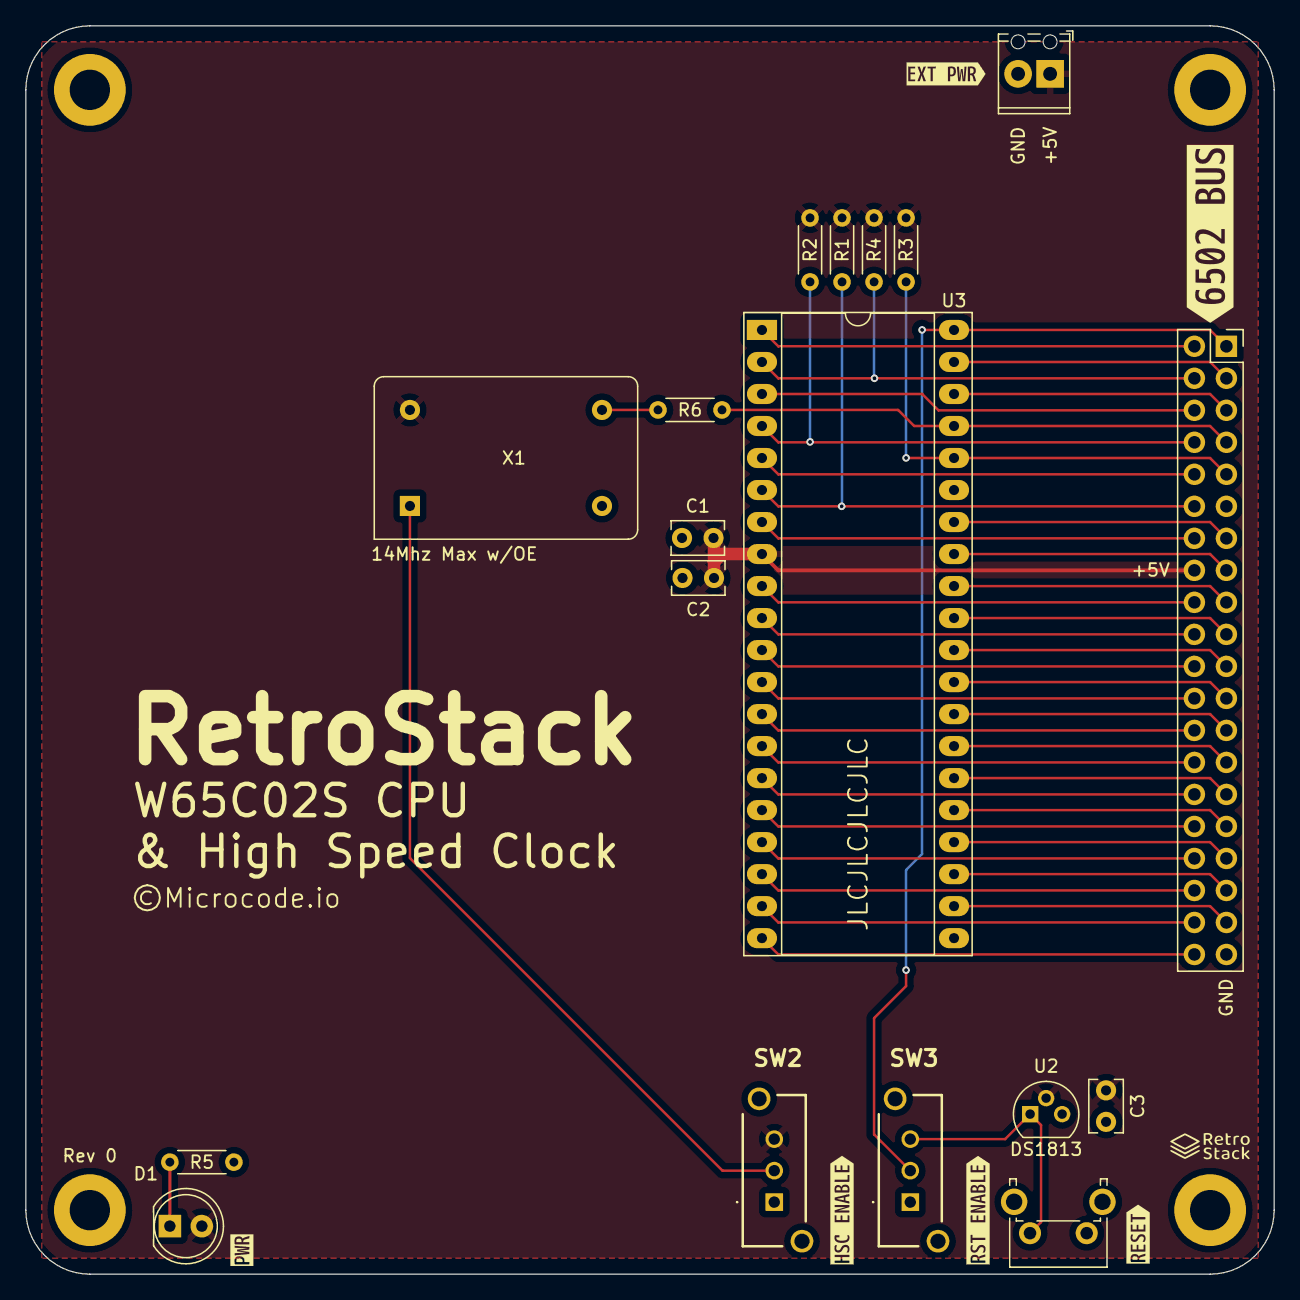
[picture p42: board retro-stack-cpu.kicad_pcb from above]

Board: 2 copper layers, 99.1 x 99.1 mm, 28 parts (0 on the bottom side), 43 nets.

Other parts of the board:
kibuzzard-642C33B0: G***; kibuzzard-642C33B0
kibuzzard-642C36EF: G***; kibuzzard-642C36EF
kibuzzard-642C367F: G***; kibuzzard-642C367F
kibuzzard-642C3375: G***; kibuzzard-642C3375
kibuzzard-642C3403: G***; kibuzzard-642C3403
kibuzzard-642888DE: G***; kibuzzard-642888DE

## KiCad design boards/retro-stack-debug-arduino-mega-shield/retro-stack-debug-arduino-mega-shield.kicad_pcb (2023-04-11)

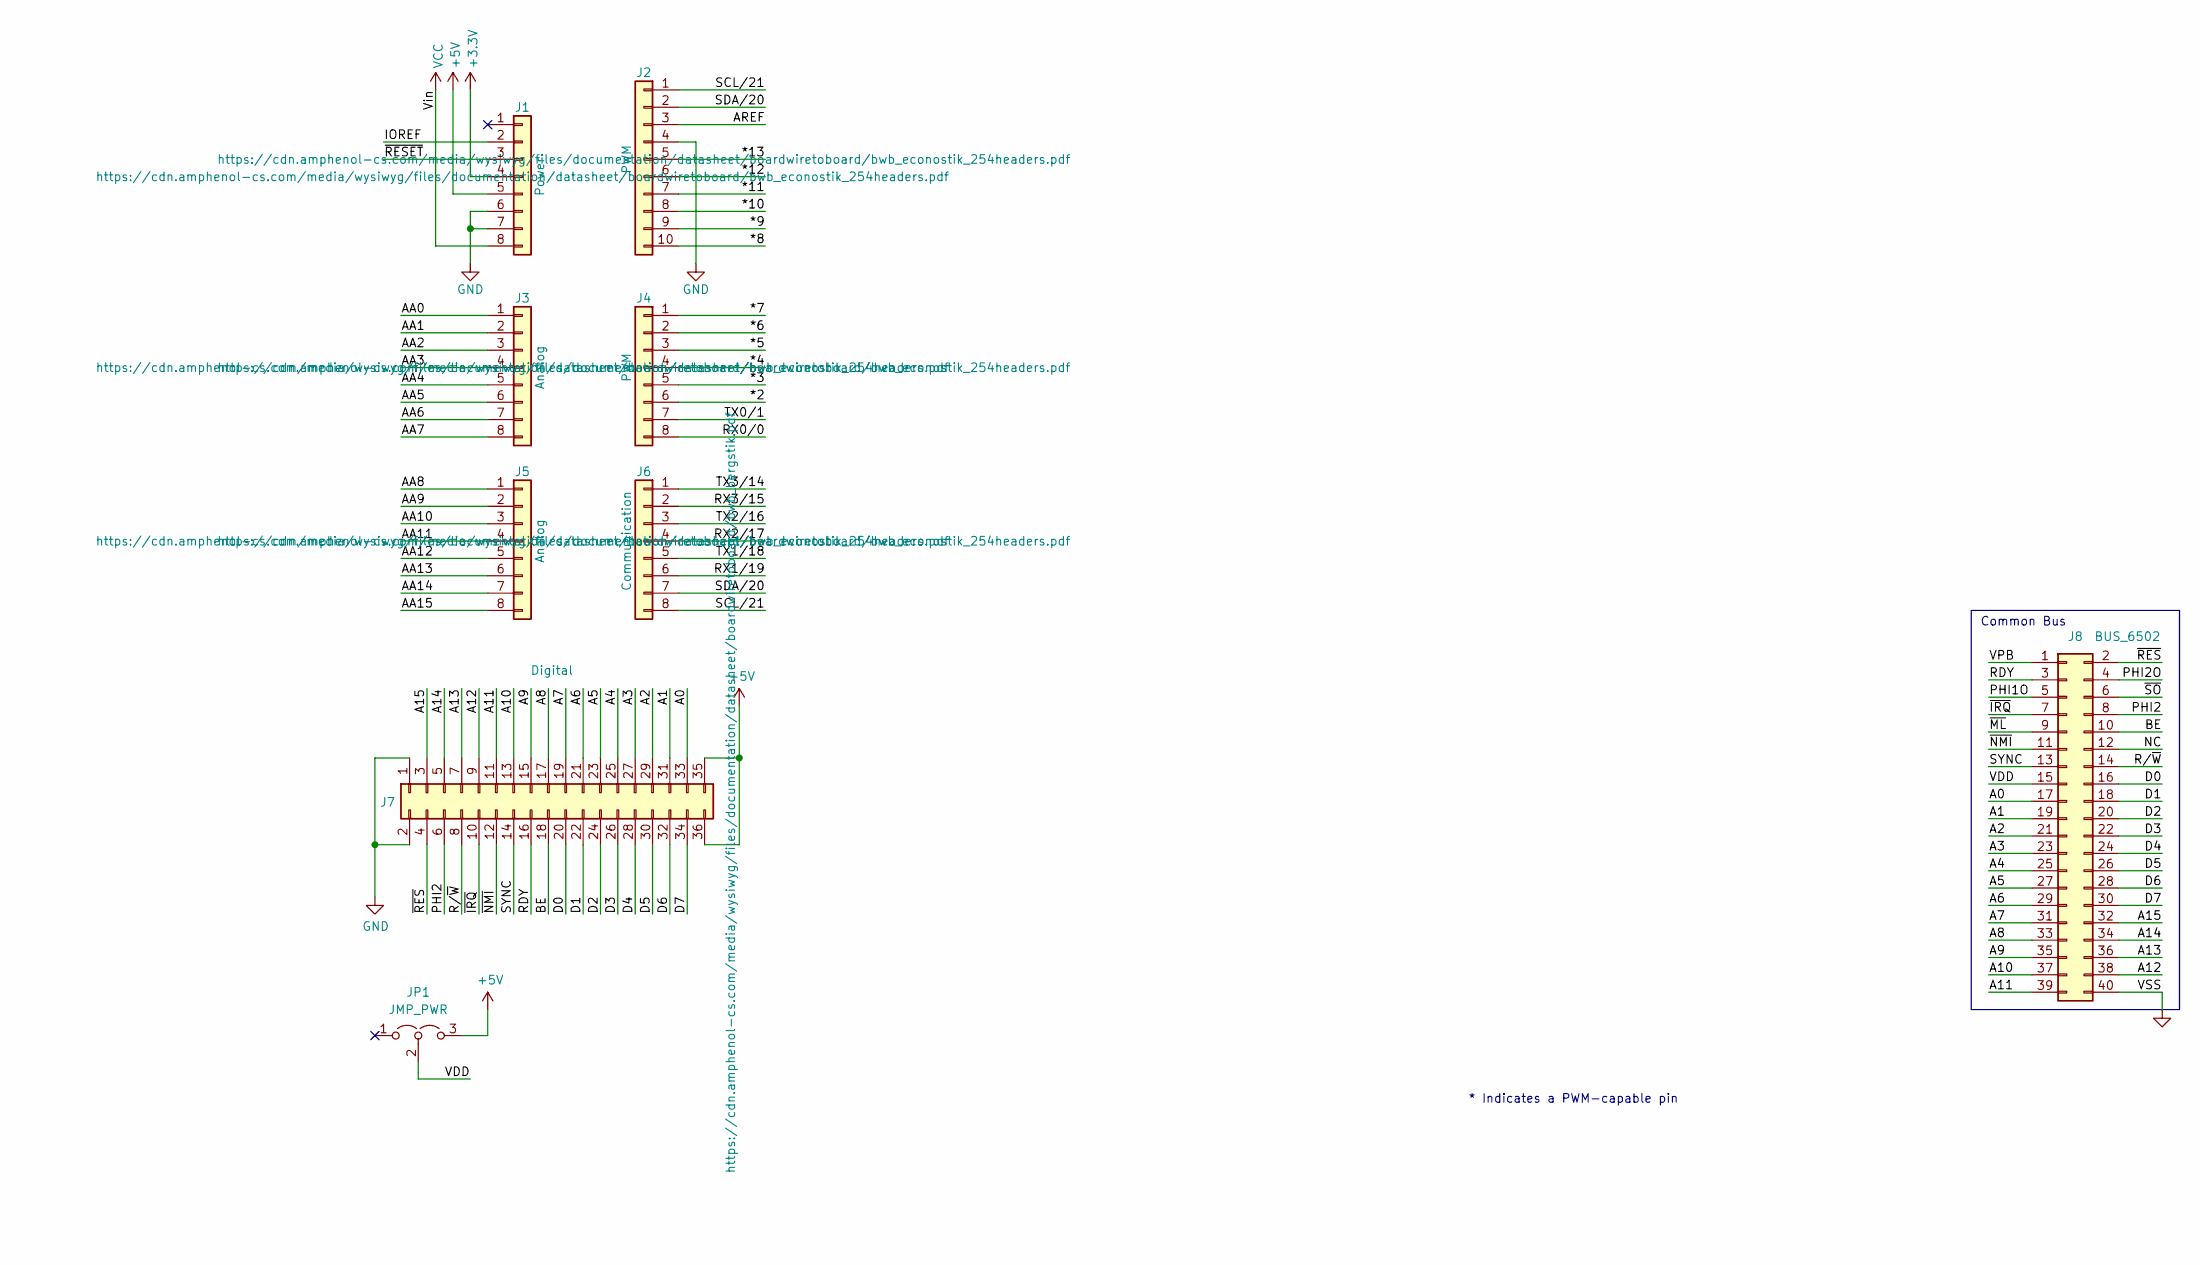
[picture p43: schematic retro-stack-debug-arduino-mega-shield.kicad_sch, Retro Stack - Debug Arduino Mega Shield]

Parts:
J1: Power; PinSocket_1x08_P2.54mm_Vertical; Mfr Part 10129378-908001BLF
J2: PWM; PinSocket_1x10_P2.54mm_Vertical; Mfr Part 10129378-910001BLF
J3, J5: Analog; PinSocket_1x08_P2.54mm_Vertical; Mfr Part 10129378-908001BLF
J4: PWM; PinSocket_1x08_P2.54mm_Vertical; Mfr Part 10129378-908001BLF
J6: Communication; PinSocket_1x08_P2.54mm_Vertical; Mfr Part 10129378-908001BLF
J7: Digital; PinSocket_2x18_P2.54mm_Vertical; Mfr Part 77313-818-36LF
J8: BUS_6502; IDC-Header_2x20_P2.54mm_Vertical; Mfr Part 30340-6002HB
JP1: JMP_PWR; PinHeader_1x03_P2.54mm_Vertical; Mfr Part 10129378-903001BLF

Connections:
+3V3: J1.4
+5V: J1.5, J7.35, J7.36, JP1.3 (B)
/*2: J4.6
/*3: J4.5
/*4: J4.4
/*5: J4.3
/*6: J4.2
/*7: J4.1
/*8: J2.10
/*9: J2.9
/*10: J2.8
/*11: J2.7
/*12: J2.6
/*13: J2.5
/A0: J7.33, J8.17
/A1: J7.31, J8.19
/A2: J7.29, J8.21
/A3: J7.27, J8.23
/A4: J7.25, J8.25
/A5: J7.23, J8.27
/A6: J7.21, J8.29
/A7: J7.19, J8.31
/A8: J7.17, J8.33
/A9: J7.15, J8.35
/A10: J7.13, J8.37
/A11: J7.11, J8.39
/A12: J7.9, J8.38
/A13: J7.7, J8.36
/A14: J7.5, J8.34
/A15: J7.3, J8.32
/AA0: J3.1
/AA1: J3.2
/AA2: J3.3
/AA3: J3.4
/AA4: J3.5
/AA5: J3.6
/AA6: J3.7
/AA7: J3.8
/AA8: J5.1
/AA9: J5.2
/AA10: J5.3
/AA11: J5.4
/AA12: J5.5
/AA13: J5.6
/AA14: J5.7
/AA15: J5.8
/AREF: J2.3
/BE: J7.18, J8.10
/D0: J7.20, J8.16
/D1: J7.22, J8.18
/D2: J7.24, J8.20
/D3: J7.26, J8.22
/D4: J7.28, J8.24
/D5: J7.30, J8.26
/D6: J7.32, J8.28
/D7: J7.34, J8.30
/IOREF: J1.2
/NC: J8.12
/PHI1O: J8.5
/PHI2: J7.6, J8.8
/PHI2O: J8.4
/RDY: J7.16, J8.3
/RX0/0: J4.8
/RX1/19: J6.6
/RX2/17: J6.4
/RX3/15: J6.2
/R/~W: J7.8, J8.14
/SCL/21: J2.1, J6.8
/SDA/20: J2.2, J6.7
/SYNC: J7.14, J8.13
/TX0/1: J4.7
/TX1/18: J6.5
/TX2/16: J6.3
/TX3/14: J6.1
/VDD: J8.15, JP1.2 (C)
/VPB: J8.1
/~IRQ: J7.10, J8.7
/~ML: J8.9
/~NMI: J7.12, J8.11
/~RESET: J1.3
/~RES: J7.4, J8.2
/~SO: J8.6
GND: J1.6, J1.7, J2.4, J7.1, J7.2, J8.40
VCC: J1.8

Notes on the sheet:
* Indicates a PWM-capable pin
Common Bus


Board: 2 copper layers, 90.2 x 53.3 mm, 16 parts (0 on the bottom side), 37 nets.

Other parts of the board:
MH1, MH2, MH3, MH4, MH5, MH6: MountingHole_3.2mm
kibuzzard-642888DE: G***; kibuzzard-642888DE

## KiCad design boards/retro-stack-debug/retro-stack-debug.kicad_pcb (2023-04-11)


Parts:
C1, C2, C3, C4: 0u1; C_Disc_D3.0mm_W2.0mm_P2.50mm; Mfr Part K104K15X7RF5TL2
D1: LED_PWR; LED_D5.0mm
D2, D3, D4, D5, D6, D7, D8, D9, D10, D11, D12, D13, D14, D15, D16, D17: 553-0121F; 5530121F; Mfr Part 553-0121F
H1, H2, H3, H4: M3; MountingHole_3.2mm_M3_ISO7380_Pad
J1: BUS_6502; PinSocket_2x20_P2.54mm_Vertical
J2: TRM_PWR; TerminalBlock_Phoenix_MPT-0,5-2-2.54_1x02_P2.54mm_Horizontal; Mfr Part 1725656
J3: BUS_DEBUG; IDC-Header_2x20_P2.54mm_Vertical; Mfr Part 30340-6002HB
R1, R2: 1k; R_Axial_DIN0204_L3.6mm_D1.6mm_P5.08mm_Horizontal; Mfr Part MBA02040C1001FCT00
RN1, RN2, RN3, RN4: 1k; R_Array_SIP9; Mfr Part 4609X-101-102LF
SW1: SW_ENABLE; LC1258EENP1RLGR; Mfr Part LC1258EENP1RLGR
U1, U2, U3: 74HC244; DIP-20_W7.62mm_LongPads; Mfr Part SN74HC244N
U4: 74HC240; DIP-20_W7.62mm_LongPads; Mfr Part SN74HC240N

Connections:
+5V: C1.1, C2.1, C3.1, C4.1, D1.2 (A), J1.16, J2.1, J3.16, R2.1, U1.20 (VCC), U2.20 (VCC), U3.20 (VCC), U4.20 (VCC)
/A0: J1.18, J3.18, U2.11 (2A3)
/A1: J1.20, J3.20, U2.13 (2A2)
/A2: J1.22, J3.22, U2.15 (2A1)
/A3: J1.24, J3.24, U2.17 (2A0)
/A4: J1.26, J3.26, U2.8 (1A3)
/A5: J1.28, J3.28, U2.6 (1A2)
/A6: J1.30, J3.30, U2.4 (1A1)
/A7: J1.32, J3.32, U2.2 (1A0)
/A8: J1.34, J3.34, U1.11 (2A3)
/A9: J1.36, J3.36, U1.13 (2A2)
/A10: J1.38, J3.38, U1.15 (2A1)
/A11: J1.40, J3.40, U1.17 (2A0)
/A12: J1.37, J3.37, U1.8 (1A3)
/A13: J1.35, J3.35, U1.6 (1A2)
/A14: J1.33, J3.33, U1.4 (1A1)
/A15: J1.31, J3.31, U1.2 (1A0)
/BE: J1.9, J3.9, U4.15 (2A1)
/D0: J1.15, J3.15, U3.11 (2A3)
/D1: J1.17, J3.17, U3.13 (2A2)
/D2: J1.19, J3.19, U3.15 (2A1)
/D3: J1.21, J3.21, U3.17 (2A0)
/D4: J1.23, J3.23, U3.8 (1A3)
/D5: J1.25, J3.25, U3.6 (1A2)
/D6: J1.27, J3.27, U3.4 (1A1)
/D7: J1.29, J3.29, U3.2 (1A0)
/ENABLE: SW1.2 (B), U1.1 (1OE), U1.19 (2OE), U2.1 (1OE), U2.19 (2OE), U3.1 (1OE), U3.19 (2OE), U4.1 (1OE), U4.19 (2OE)
/LA0: D17.2, U2.9 (2Y3)
/LA1: D16.2, U2.7 (2Y2)
/LA2: D15.2, U2.5 (2Y1)
/LA3: D14.2, U2.3 (2Y0)
/LA4: D13.2, U2.12 (1Y3)
/LA5: D12.2, U2.14 (1Y2)
/LA6: D11.2, U2.16 (1Y1)
/LA7: D10.2, U2.18 (1Y0)
/LA8: D9.2, U1.9 (2Y3)
/LA9: D8.2, U1.7 (2Y2)
/LA10: D7.2, U1.5 (2Y1)
/LA11: D6.2, U1.3 (2Y0)
/LA12: D5.2, U1.12 (1Y3)
/LA13: D4.2, U1.14 (1Y2)
/LA14: D3.2, U1.16 (1Y1)
/LA15: D2.2, U1.18 (1Y0)
/LD0: D17.4, U3.9 (2Y3)
/LD1: D16.4, U3.7 (2Y2)
/LD2: D15.4, U3.5 (2Y1)
/LD3: D14.4, U3.3 (2Y0)
/LD4: D13.4, U3.12 (1Y3)
/LD5: D12.4, U3.14 (1Y2)
/LD6: D11.4, U3.16 (1Y1)
/LD7: D10.4, U3.18 (1Y0)
/L_BE: D7.4, U4.5 (2Y1)
/L_IRQ: D4.4, U4.14 (1Y2)
/L_ML: D8.4, U4.7 (2Y2)
/L_NMI: D5.4, U4.12 (1Y3)
/L_RES: D2.4, U4.18 (1Y0)
/L_RW: D3.4, U4.16 (1Y1)
/L_SYNC: D6.4, U4.3 (2Y0)
/L_VPB: D9.4, U4.9 (2Y3)
/NC: J1.11, J3.11
/PHI1O: J1.6, J3.6
/PHI2: J1.7, J3.7
/PHI2O: J1.3, J3.3
/RDY: J1.4, J3.4
/R/~W: J1.13, J3.13, U4.4 (1A1)
/SYNC: J1.14, J3.14, U4.17 (2A0)
/VPB: J1.2, J3.2, U4.11 (2A3)
/~IRQ: J1.8, J3.8, U4.6 (1A2)
/~ML: J1.10, J3.10, U4.13 (2A2)
/~NMI: J1.12, J3.12, U4.8 (1A3)
/~RES: J1.1, J3.1, U4.2 (1A0)
/~SO: J1.5, J3.5
GND: C1.2, C2.2, C3.2, C4.2, H1.1, H2.1, H3.1, H4.1, J1.39, J2.2, J3.39, R1.2, RN1.1 (common), RN2.1 (common), RN3.1 (common), RN4.1 (common), SW1.1 (A), U1.10 (GND), U2.10 (GND), U3.10 (GND), U4.10 (GND)
unnamed: D1.1 (K), R1.1
unnamed: D2.1, RN1.3 (R2)
unnamed: D2.3, RN1.2 (R1)
unnamed: D3.1, RN1.5 (R4)
unnamed: D3.3, RN1.4 (R3)
unnamed: D4.1, RN1.7 (R6)
unnamed: D4.3, RN1.6 (R5)
unnamed: D5.1, RN1.9 (R8)
unnamed: D5.3, RN1.8 (R7)
unnamed: D6.1, RN2.3 (R2)
unnamed: D6.3, RN2.2 (R1)
unnamed: D7.1, RN2.5 (R4)
unnamed: D7.3, RN2.4 (R3)
unnamed: D8.1, RN2.7 (R6)
unnamed: D8.3, RN2.6 (R5)
unnamed: D9.1, RN2.9 (R8)
unnamed: D9.3, RN2.8 (R7)
unnamed: D10.1, RN3.3 (R2)
unnamed: D10.3, RN3.2 (R1)
unnamed: D11.1, RN3.5 (R4)
unnamed: D11.3, RN3.4 (R3)
unnamed: D12.1, RN3.7 (R6)
unnamed: D12.3, RN3.6 (R5)
unnamed: D13.1, RN3.9 (R8)
unnamed: D13.3, RN3.8 (R7)
unnamed: D14.1, RN4.3 (R2)
unnamed: D14.3, RN4.2 (R1)
unnamed: D15.1, RN4.5 (R4)
unnamed: D15.3, RN4.4 (R3)
unnamed: D16.1, RN4.7 (R6)
unnamed: D16.3, RN4.6 (R5)
unnamed: D17.1, RN4.9 (R8)
unnamed: D17.3, RN4.8 (R7)
unnamed: R2.2, SW1.3 (C)

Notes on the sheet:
Debug Bus
External Power
Common Bus
Power LED
Mounting Holes


Board: 2 copper layers, 99.1 x 99.1 mm, 42 parts (0 on the bottom side), 107 nets.

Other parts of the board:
kibuzzard-642C36EF: G***; kibuzzard-642C36EF
kibuzzard-642C367F: G***; kibuzzard-642C367F
kibuzzard-642888DE: G***; kibuzzard-642888DE

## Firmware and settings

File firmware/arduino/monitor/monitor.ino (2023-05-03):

// Copyright 2023 Greg Coonrod
// 
// Licensed under the Apache License, Version 2.0 (the "License");
// you may not use this file except in compliance with the License.
// You may obtain a copy of the License at
// 
//     http://www.apache.org/licenses/LICENSE-2.0
// 
// Unless required by applicable law or agreed to in writing, software
// distributed under the License is distributed on an "AS IS" BASIS,
// WITHOUT WARRANTIES OR CONDITIONS OF ANY KIND, either express or implied.
// See the License for the specific language governing permissions and
// limitations under the License.

#include "RetroStackDebug.h"

volatile uint8_t dataDirection = INPUT;

void setup() {
    // Set up the address pins
    setAddressDirection(INPUT);

    // Set up the data pins
    setDataDirection(dataDirection);

    // Set up the control pins
    //setControlDirections(0xff, INPUT);
    pinMode(2, INPUT);

    // Set up the interrupt
    attachInterrupt(digitalPinToInterrupt(2), onClockRise, RISING);

    // Set up the serial port
    Serial.begin(115200);
    Serial.println("Setup complete.");
}

void loop() {

}

void onClockRise() {
    sei();
    // Default data direction is input
    if (dataDirection == OUTPUT) {
        dataDirection = INPUT;
        setDataDirection(dataDirection);
    }

    // Read address and data
    uint8_t data;
    uint16_t address = readAddress();
    // If data is in ROM, set data direction to output
    // and write the data to the bus
    // if (inROM(address)) {
    //     data = readROM(address);
    //     dataDirection = OUTPUT;
    //     setDataDirection(dataDirection);
    //     writeData(data);
    //     Serial.print(F("ROM: "));
    //     printBinaryByte(data);
    //     Serial.println();
    // } else {
    //     data = readData();
    // }

    data = readData();


    char output[15];
    printBinaryWord(address);
    Serial.print("   ");
    printBinaryByte(data);
    sprintf(output, "   %04x  %c %02x", address, digitalRead(RWB) ? 'r' : 'W', data);
    Serial.println(output);
    cli();
}

void printBinaryWord(uint16_t word) {
    for (int n = 0; n < 16; n += 1) {
        int bit = (word >> (15 - n)) & 1;
        Serial.print(bit);
    }
}

void printBinaryByte(uint8_t byte) {
    for (int n = 0; n < 8; n += 1) {
        int bit = (byte >> (7 - n)) & 1;
        Serial.print(bit);
    }
}

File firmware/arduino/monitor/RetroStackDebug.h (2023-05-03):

// Copyright 2023 Greg Coonrod
// 
// Licensed under the Apache License, Version 2.0 (the "License");
// you may not use this file except in compliance with the License.
// You may obtain a copy of the License at
// 
//     http://www.apache.org/licenses/LICENSE-2.0
// 
// Unless required by applicable law or agreed to in writing, software
// distributed under the License is distributed on an "AS IS" BASIS,
// WITHOUT WARRANTIES OR CONDITIONS OF ANY KIND, either express or implied.
// See the License for the specific language governing permissions and
// limitations under the License.

#include <stdint.h>

#ifndef RETROSTACKDEBUG_H
#define RETROSTACKDEBUG_H

// Define the memory ranges
#define RAM_START 0x0000
#define RAM_END   0x3FFF
#define RAM_SIZE  (RAM_END - RAM_START + 1)
#define inRAM(address) (address >= RAM_START && address <= RAM_END)

#define ROM_START 0x8000
#define ROM_END   0xFFFF
#define ROM_SIZE  (ROM_END - ROM_START + 1)
#define inROM(address) (address >= ROM_START && address <= ROM_END)

// Define the address and data pins

// reverse the order of the address pins
//const char ADDR[] = {22, 24, 26, 28, 30, 32, 34, 36, 38, 40, 42, 44, 46, 48, 50, 52};
const char ADDR[] = {52, 50, 48, 46, 44, 42, 40, 38, 36, 34, 32, 30, 28, 26, 24, 22};

//const char DATA[] = {37, 35, 33, 31, 29, 27, 25, 23};
const char DATA[] = {23, 25, 27, 29, 31, 33, 35, 37};


// Define the control pins
#define BE      39
#define RDY     41
#define SYNC    43
#define NMIB    45
#define IRQB    47
#define RWB     49
#define PHI2    2
#define RESB    53

// Op Codes
#define NOP 0xEA

// Define functions
uint8_t readROM(uint16_t address);
uint8_t readRAM(uint16_t address);
uint16_t readAddress();
void setDataDirection(int direction);
void setAddressDirection(int direction);
void setControlDirections(uint8_t mask, uint8_t direction);
uint8_t readData();
void writeData(uint8_t data);


#endif

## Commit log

2023-04-01 Initial template setup.
    [retro-stack-template.kicad_pcb, retro-stack-template.kicad_sch]
2023-04-01 Initial board template design.
    [retro-stack-template.kicad_pcb, retro-stack-template.kicad_sch]
2023-04-02 Completed initial schematic and parts selection.
    [EG1213.step, EG1213.stp, LVR125S-240.step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]
2023-04-03 Rev 0 of the power and clock card ordered.
    [retro-stack-power-clock.kicad_pcb, retro-stack-power-clock.kicad_sch]
2023-04-04 CPU board rev0 schematic and layout complete.
    [retro-stack-cpu.kicad_pcb, retro-stack-cpu.kicad_sch]
2023-04-05 Rev 0 schematic and pcb complete for RAM/ROM board.
    [ATF16V8B-15PU.step, ATF16V8B-15PU.stp, retro-stack-cpu.kicad_pcb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]
2023-04-06 Update template
    [retro-stack-template.kicad_pcb, retro-stack-template.kicad_sch]
2023-04-07 Initial schematic and layout complete for VIA board.
    [retro-stack-via.kicad_pcb, retro-stack-via.kicad_sch]
2023-04-11 Initial design and layout of arduino debug shield.
    [retro-stack-debug-arduino-mega-shield.kicad_pcb, retro-stack-debug-arduino-mega-shield.kicad_sch]
2023-04-11 Minor updates.
    [553-0121F.step, 553-0121F.stp]
2023-04-11 Completed rev 0 of cpu, debug, and debug shield boards.
    [retro-stack-cpu.kicad_pcb, retro-stack-cpu.kicad_sch, retro-stack-debug-arduino-mega-shield.kicad_pcb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]
2023-04-11 Update documentation for recently completed board revisions.
    [retro-stack-debug-arduino-mega-shield.kicad_sch, retro-stack-debug.kicad_sch]
2023-04-14 Update template to use right angle idc instead of vertical pin socket.
    [retro-stack-template.kicad_pcb, retro-stack-template.kicad_sch]
2023-04-24 Start work on a PLD test circuit.
    [pld-test.kicad_pcb, pld-test.kicad_sch]
2023-04-25 First working memory pld coded.
    [pld-test.kicad_sch]
2023-04-25 Update ram/rom to only use pld.
    [retro-stack-ram-rom.kicad_pcb]
2023-04-27 Initial PLD test and RAM/ROM board.
    [24-6554-10.step, 24-6554-10.stp, 28-6554-10.step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]
2023-05-03 Update documentation to include latest boards and firmware.
2023-05-10 New assembly programs and docs updates.
2023-06-14 add latest set of kicad parts
    [0PTF0078P.step, 0PTF0078P.stp, 12401832E402A.step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]
2023-06-14 Minor board updates and nano-acia
    [basic-nano-acia.kicad_pcb, basic-nano-acia.kicad_sch]
2023-07-12 Rev 0 of min sbc complete. Many issues. Start new Rev.
    [6502-min-sbc.kicad_pcb, 6502-min-sbc.kicad_sch]

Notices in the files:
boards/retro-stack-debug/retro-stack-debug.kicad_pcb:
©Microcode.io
